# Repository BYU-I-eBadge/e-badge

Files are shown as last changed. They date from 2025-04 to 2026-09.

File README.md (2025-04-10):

# eBadge

**eBadge** is a customizable, hackable electronics badge designed for students to explore, build, and learn throughout their academic journey. It’s more than just a badge—it's a personal electronics lab, wearable project canvas, and long-term learning tool.

## Features

- Custom PCB with microcontroller 
- Modular peripherals: LEDs, sensors, buttons, displays, etc.
- Fully programmable with open-source firmware
- Designed for learning — from blinking LEDs to building full apps
- Battery-powered & portable — perfect for hacking on the go

## What’s in This Repo?

```bash
e-badge/
├── docs/           # Project documentation, setup guides, and images
├── hardware/       # Schematics, PCB layouts, BOMs, and 3D models
├── firmware/       # Embedded code for the badge's microcontroller
├── software/       # Host-side apps, test tools, or configurators
├── assets/         # Logos, badge graphics, and artwork
├── test/           # Scripts for testing hardware and firmware
├── LICENSE-CODE
├── LICENSE-HARDWARE
├── LICENSE-DOCS
├── README.md
└── .gitignore
```
## License

- **Hardware** – [CERN-OHL-S v2.0](./LICENSE-HARDWARE)
- **Firmware/Code** – [MIT License](./LICENSE-CODE)
- **Docs & Assets** – [CC BY-SA 4.0](./LICENSE-DOCS)

## Contributors

- Nathan Jack (jackn@byui.edu)
- Lynn Watson (watsonl@byui.edu)
- Jason Allred (allredjas@byui.edu)
- Richard Grimmett (grimmettr@byui.edu)
- Carl Gibbons (gibbonsc@byui.edu)
- Craig Lindstrom (lindstromc@byui.edu)
- Gary Godderidge (godderidgeg@byui.edu)
- Matt Manley (manleym@byui.edu)

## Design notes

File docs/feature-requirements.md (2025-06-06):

# eBadge Featureset

### MCU Features
* Wi-Fi/Bluetooth Capable
* JTAG single step debugging
* Dual Core (Defaults to Single Core)
* Supports MicroPython, Arduino IDE and RTOS!

### On-board Peripherals
* SPI Multicolor Screen (refresh >= 30 Hz)
* 6X Buttons with pull-down resistor configuration
* 2 LEDs
* 1 Tri-colored LED
* Speaker
* SD Card Slot
* Open slot of analog stick from Adafruit

### Interfaces
* 4pin JST/Grove Connectors 
* 2X Minibadge Connectors
* Lots of generic female headers!

### Additional Features
# Detailed Silk Screen
# Battery hook in + charging circuitry

### Unconfirmed Features
# Accelerometer
# Gyroscope
# RFID/NFC

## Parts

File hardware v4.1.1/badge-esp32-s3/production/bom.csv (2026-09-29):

Designator | Footprint | Quantity | Value | LCSC Part #
AL1, AL10, AL11, AL12, AL13, AL14, AL15, AL16, AL17, AL18, AL19, AL2, AL20, AL21, AL22, AL23, AL24, AL3, AL4, AL5, AL6, AL7, AL8, AL9 | LED-SMD_4P-SK6805MICRO-J | 24 | SK6805MICRO-J | C2909056
BUZZER1 | BUZ-SMD_L5.0-W5.5-P4.60 | 1 | MLT-5020 | C94598
C1, C12, C24, C39, C5, C6, C7 | C_0603 | 7 | 10uF | C96446
C10, C11, C25, C3, C35, C36, C4 | C_0402 | 7 | 100nF | C1525
C14, C2 | C_0603 | 2 | 100nF | C14663
C15, C16, C32, C33, C8, C9 | C_0402 | 6 | 1uF | C52923
C18, C19, C20, C21, C22, C23 | C_0603 | 6 | 1uF | C15849
C26 | C_0603 | 1 | 4.7uF | C19666
C28, C29, C30, C31, C38, C40 | C_0805 | 6 | 22uF | C296720
C34, C41, C44 | C_0402 | 3 | 100nF | C307331
C37 | C0603 | 1 | TMK107BBJ106MA-T | C386081
C42, C43, C45 | C_0805 | 3 | 10uF | C440198
CARD1 | TF-SMD_TF-PUSH | 1 | TF PUSH | C393941
CN1 | CONN-SMD_B4B-PH-SM4-TB-LF-SN | 1 | B4B-PH-SM4-TB (LF)(SN) | C160354
D1, D14, D19 | D_0603 | 3 | Red | C2286
D10 | D_SOD-523 | 1 | B5819WT | C7502714
D11 | SOD-523_L1.2-W0.8-LS1.6-RD-1 | 1 | MM5Z9V1T1G | C242268
D12 | D_0805 | 1 | Green | C2297
D13 | SMA_L4.3-W2.7-LS5.1-BI | 1 | SMAJ13CA | C19077534
D15, D20 | SOD-523F_L1.2-W0.8-LS1.7-RD | 2 | MM5Z5V1T1G | C146754
D16, D5 | D_SOD-123 | 2 | B0520W | C7502707
D17, D18 | SMAF_L3.5-W2.6-LS4.7-RD | 2 | SS32F_C719168 | C719168
D2, D3, D4, D6, D7, D8 | SOD-523_L1.2-W0.8-LS1.6-BI | 6 | LESD5D5.0CT1G | C5199850
D9 | SMA_L4.3-W2.7-LS5.1-BI | 1 | SMAJ5.0CA_C116601 | C116601
J1, J2 | TYPE-C-SMD_HX-TYPE-C-16PIN | 2 | Connector, USB-TYPE-C-16P | C2927039
J11 | PinSocket_2x03_P2.54mm_Vertical | 1 | Conn_02x03_Odd_Even | C541853
J12, J14, J15, J5 | PinSocket_1x02_P2.54mm_Vertical | 4 | Conn_01x02_Socket | C7499322
J13, J6 | PinSocket_1x04_P2.54mm_Vertical | 2 | Conn_01x04_Socket | C2718488
J3, J9 | PinSocket_2x06_P2.54mm_Vertical | 2 | Conn_02x06_Odd_Even | C5307342
J4 | PinSocket_2x15_P2.54mm_Vertical | 1 | Conn_02x15_Odd_Even | C7499350
J7, J8 | PinSocket_1x08_P2.54mm_Vertical | 2 | Conn_01x08_Socket | C42385698
L1 | IND-SMD_L4.0-W4.0 | 1 | ANR4030T3R9M | C6808101
L2 | L0805 | 1 | MPZ2012S101AT000 | C15957
L4 | IND-SMD_L4.1-W4.1_SPM40XX | 1 | FTC404020S1R5MGCA | C39676069
LED1 | LED-ARRAY-SMD_L3.7-W3.5-P1.10-TL | 1 | RS-3535MWAM | C842778
P1 | CONN-TH_2P-P2.00_PH-2A_C2319 | 1 | PH-2A_C2319 | C2319
P2 | FPC-SMD_12P-L11.5-W5.4-P0.50 | 1 | FPC 0.5MM 12P Pull type H2.0mm Pick up | C11086
P3 | CONN-TH_2P-P3.81_KF124-3.81-2P | 1 | WJ124-3.81-2P | C69811
Q1, Q2 | Q_SOT-23 | 2 | SS8050 200-350 | C2150
Q10 | SOT-23-3_L2.9-W1.6-P1.90-LS2.8-BR-CW | 1 | DMN3150L-7 | C156268
Q3 | DFN-3L_L1.0-W0.6-P0.65-BR | 1 | AP1606 | C2849580
Q5 | DTC114EE | 1 | DTC114E | C94400
Q7, Q8, Q9 | SOT-23-3_L2.9-W1.3-P1.90-LS2.4-BR | 3 | AO3415_C54938718 | C54938718
R1, R11, R12, R64 | R_0402 | 4 | 0Ω | C17168
R10, R13, R14, R17, R44, R46, R48, R6, R66, R68, R69, R70 | R_0402 | 12 | 10kΩ | C25744
R15, R16, R55 | R_0402 | 3 | 470Ω | C25117
R18, R20, R40, R47, R49, R50, R51, R52 | R_0402 | 8 | 100Ω | C25076
R2 | RES-ADJ-TH_3362P | 1 | 3362P-1-501_C48997906 | C48997906
R21, R24 | R_0402 | 2 | 47Ω | C25118
R22, R54 | R_0402 | 2 | 300Ω | C25102
R23 | JOYTICK-TH_YF16-DFL7.2-B5KO-45-10-B5KO-55--RG-A22 | 1 | YF16-FL7.2-B5KA(45-10)-R-A28 | C37323739
R25, R9 | R_0402 | 2 | 1kΩ | C11702
R26 | R_0402 | 1 | 2.2kΩ | C25879
R27, R28, R29, R30, R31, R32, R33, R34, R35, R36, R37, R38 | R_0603 | 12 | 10kΩ | C25804
R3, R4 | R_0402 | 2 | 5.1kΩ | C25905
R39, R53, R56, R60, R62 | R_0402 | 5 | 100kΩ | C25741
R41 | R_0402 | 1 | 150kΩ | C25755
R42 | 0402 | 1 | 27Ω
R43, R45 | R_0402 | 2 | 4.7kΩ | C25900
R5 | R0402 | 1 | 910k | C2909391
R58, R61 | R_0402 | 2 | 3.3kΩ | C25890
R59, R71 | R_0402 | 2 | 1MΩ | C26083
R63 | R_0402 | 1 | 39kΩ | C25783
R65 | R_0402 | 1 | 12kΩ | C25752
R67 | R_0402 | 1 | 68kΩ | C36871
R7 | R_0402 | 1 | 22kΩ | C25768
R8 | R_0402 | 1 | 47kΩ | C25792
SW1, SW2 | SW-SMD_L3.9-W3.0-P4.45 | 2 | TS-1088-AR02016 | C720477
SW10 | SW-TH_SK22D02G5 | 1 | SK22D02G5 | C22435630
SW4, SW5, SW6, SW7, SW8, SW9 | SW-TH_4P-L6.0-W6.0-P4.50-LS6.5 | 6 | TS665CJ | C393938
U1 | ESP32-S2-MINI-1 | 1 | ESP32-S3-MINI-1-N4R2 | C3013941
U11, U12 | SOT-23-6_L2.9-W1.6-P0.95-LS2.8-BL | 2 | SY6288F1ABC | C2875458
U18 | QFN-16_L3.0-W3.0-P0.50-TL_MMA8452QR1 | 1 | MMA8452QR1_C11360 | C11360
U2 | VQFN-HR-15_L3.0-W2.5-P0.50-BL_TPS63070RNMR | 1 | TPS630701RNMR | C2876599
U3 | QFN-28_L5.0-W5.0-P0.50-TL-EP3.3 | 1 | CP2102N-A02-GQFN28R | C964632
U4 | ESOP-8_L4.9-W3.9-P1.27-LS6.0-BL-EP | 1 | TP4056 | C16581
U5 | VQFN-HR-12_L2.5-W2.0-P0.50-BL | 1 | TPS2121RUXR | C485916
U6 | CONN-SMD_4P-P1.00_MEGASTAR_ZX-SH1.0-4PWT | 1 | ZX-SH1.0-4PWT | C7430446
U8 | X2QFN-12_L1.6-W1.6-P0.40-BL | 1 | TUSB321AIRWBR | C2674046
U9 | TSOT-26_L2.9-W1.6-P0.95-LS2.8-BL | 1 | AP63203WU-7 | C780769

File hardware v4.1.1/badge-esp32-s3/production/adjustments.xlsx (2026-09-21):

Designator | Man. Part | LCSC Part | New Man. Part | New LCSC Part
U11,U12 | SY6288F1ABC |  | SY6863B3ABC | C2687365
U9 | AP63201WU-7 |  | AP63203WU-7 | C780769
Q7,Q8,Q9 |  |  |  | C54938718

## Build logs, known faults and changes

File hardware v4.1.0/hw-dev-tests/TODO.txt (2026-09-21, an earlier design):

Change USB SRC LED resistor
Fix power rail dropping when changing pwr sources

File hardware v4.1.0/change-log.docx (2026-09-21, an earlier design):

E-Badge 4.1.0

Features

- Dual power roles on USB-CDC-DRD port
- VIN input from 2.8V to 16V
- Undervoltage and overvoltage protection.
- Overcurrent protection.
- 10W collective power budget from 5V and 3.3V rail. [^1]

Changes

- Adjusted Joystick footprint to match 3d model.
- Moved CN1 connector to not interfere with joystick.
- Adjusted resistors for RGB LED to lower brightness.
- Adjusted resistors for Red LED to increase brightness.
- Changed out previous 16mA per color channel Addressable LEDs for 5mA per color channel LEDs.
- Changed potentiometer to 500ohm 1 turn potentiometer. (This should make it much more responsive). [^2]
- Selected power path components to allow for increased current through the board. (More than 2A of current draw).
- Added automatic USB power role switching. The board can be powered from any source and source up 500mA of current to the USB-CDC-DRD port.
- Added VIN screw terminal input with respective components to allow for an external input voltage supply of 2.8V to 16V.
- Swapped 3.3V LDO for buck converter.
- Changed VBAT on E-badge to 5V. [^3]

[^1] The 5V rail can source 10W (5V at 2A). The 3.3V rail can source 6.6W (3.3V at 2A) but draws power from the 5V rail pulling from the 10W budget.
[^2] In my tests the buzzer seemed sufficiently load. But I was driving it with stm32 PWM rather than the ESP. Also, the buzzer is designed to resonate a 4khz so any other frequency will be significantly attenuated.
[^3] Changing this to 5V meets the E-badge specifications and allows for simplified routing and power management. Matthew Spotten

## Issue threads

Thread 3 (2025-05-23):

Additional I/O Pins

hyperdriveguy, 2025-05-23:

EverettButtars, 2025-06-02:
Slightly related, Here's a dump of potential extra sensors/parts that could be fun. All require only I2C + ground, but some offer additional functionality with more pins (typically interrupts).

Accelerometer: https://www.digikey.com/en/products/detail/memsic-inc/MXC4005XC/10322569
Rotary sensor: https://www.digikey.com/en/products/detail/infineon-technologies/TLV493DA1B6HTSA2/5887140
RFID/NFC: https://www.digikey.com/en/products/detail/stmicroelectronics/ST25DV64KC-IE6S3/14645761
Digi-Pot: https://www.digikey.com/en/products/detail/microchip-technology/MCP4561-502E-MS/2059913

Haven't found parts but off the top of my head:
Light sensors:
LED strip
Humidity/Moisture
Temprature

On another related front, here is Digikey's section on daughter boards. https://www.digikey.com/en/products/filter/expansion-boards-daughter-cards/797?s=N4IgTCBcDaIHIDEDCIC6BfIA

EverettButtars, 2025-06-03:
One thing I noticed on the pybadge was these headers on the back

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

These are pretty low profile and hook into almost all IO on the board. Something similar could be nice. Either under the screen for minimal impact due to through hole, or on the edge for bread board connection could be good. It could also be a solution to some 'plug and play' mini-badge-esc things.

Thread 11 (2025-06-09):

Alpha Board Software Test

hyperdriveguy, 2025-06-09:
Make test firmware to expose hardware bugs in our design.

Closed 2025-06-23.

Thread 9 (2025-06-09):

Cost Optimization For Beta Board

hyperdriveguy, 2025-06-09:
We need to find ways to cut costs for this version for both small scale and full scale production.

hyperdriveguy, 2025-06-09:
Changes that were made taking this consideration into account include:
* Switching from a ESP32-S3-WROOM-1 to ESP32-S3-MINI-1 package
* Selecting basic parts over extended parts
* Selecting high availability parts to replace less available and more costly parts

Closed 2025-06-30.

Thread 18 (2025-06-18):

Fix Alphaboard

ThirstyShades, 2025-06-18:
The Alpha board was laid out incorrectly and needs traces to be fixed.

Specifically, the UART and the linear regulator, as well as any other issues that might arise, are addressed in hopes of interfacing with the SPI screen.

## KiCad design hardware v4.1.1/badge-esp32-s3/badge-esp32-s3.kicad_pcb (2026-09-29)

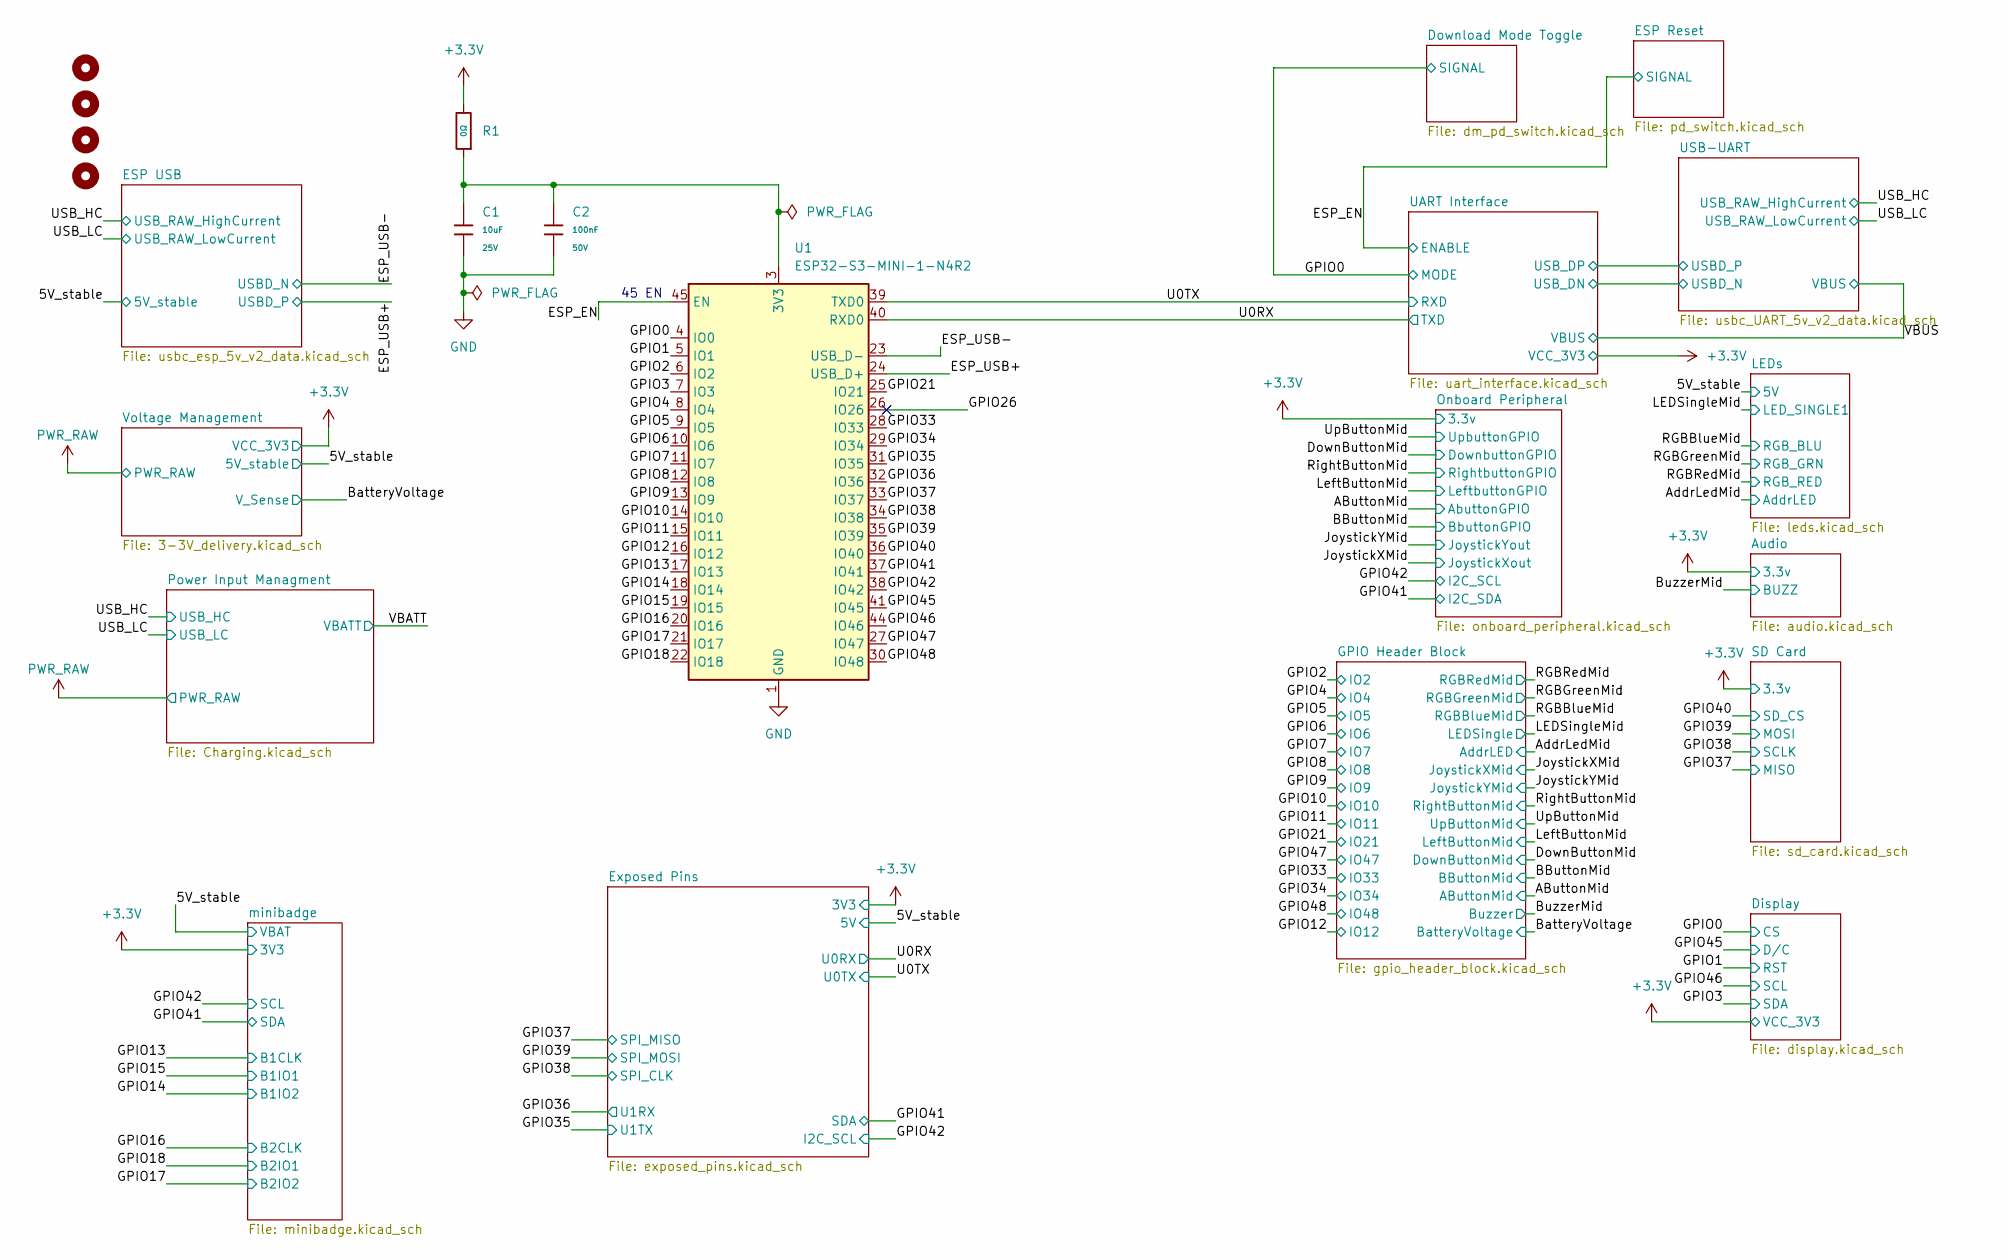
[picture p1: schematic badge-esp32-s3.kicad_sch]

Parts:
C1: 10uF; C_0603; Voltage Rated 25V; Tolerance ±20%; Part CL10A106MA8NRNC; LCSC C96446
C2: 100nF; C_0603; Voltage Rated 50V; Tolerance ±10%; Part CC0603KRX7R9BB104; LCSC C14663
H1, H2, H3, H4: MountingHole; MountingHole_3.2mm_M3_ISO7380_Pad_TopBottom
R1: 0Ω; R_0402; Overload Voltage (Max) 50V; Tolerance ±1%; Part 0402WGF0000TCE; LCSC C17168
U1: ESP32-S3-MINI-1-N4R2; ESP32-S2-MINI-1; LCSC Part C3013941

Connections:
+3.3V: R1.2; also elsewhere on the board
/ESP_EN: U1.45 (EN); also elsewhere on the board
/ESP_USB+: U1.24 (USB_D+); also elsewhere on the board
/ESP_USB-: U1.23 (USB_D-); also elsewhere on the board
/GPIO0: U1.4 (IO0); also elsewhere on the board
/GPIO1: U1.5 (IO1); also elsewhere on the board
/GPIO2: U1.6 (IO2); also elsewhere on the board
/GPIO3: U1.7 (IO3); also elsewhere on the board
/GPIO4: U1.8 (IO4); also elsewhere on the board
/GPIO5: U1.9 (IO5); also elsewhere on the board
/GPIO6: U1.10 (IO6); also elsewhere on the board
/GPIO7: U1.11 (IO7); also elsewhere on the board
/GPIO8: U1.12 (IO8); also elsewhere on the board
/GPIO9: U1.13 (IO9); also elsewhere on the board
/GPIO10: U1.14 (IO10); also elsewhere on the board
/GPIO11: U1.15 (IO11); also elsewhere on the board
/GPIO12: U1.16 (IO12); also elsewhere on the board
/GPIO13: U1.17 (IO13); also elsewhere on the board
/GPIO14: U1.18 (IO14); also elsewhere on the board
/GPIO15: U1.19 (IO15); also elsewhere on the board
/GPIO16: U1.20 (IO16); also elsewhere on the board
/GPIO17: U1.21 (IO17); also elsewhere on the board
/GPIO18: U1.22 (IO18); also elsewhere on the board
/GPIO21: U1.25 (IO21); also elsewhere on the board
/GPIO26: U1.26 (IO26)
/GPIO33: U1.28 (IO33); also elsewhere on the board
/GPIO34: U1.29 (IO34); also elsewhere on the board
/GPIO35: U1.31 (IO35); also elsewhere on the board
/GPIO36: U1.32 (IO36); also elsewhere on the board
/GPIO37: U1.33 (IO37); also elsewhere on the board
/GPIO38: U1.34 (IO38); also elsewhere on the board
/GPIO39: U1.35 (IO39); also elsewhere on the board
/GPIO40: U1.36 (IO40); also elsewhere on the board
/GPIO41: U1.37 (IO41); also elsewhere on the board
/GPIO42: U1.38 (IO42); also elsewhere on the board
/GPIO45: U1.41 (IO45); also elsewhere on the board
/GPIO46: U1.44 (IO46); also elsewhere on the board
/GPIO47: U1.27 (IO47); also elsewhere on the board
/GPIO48: U1.30 (IO48); also elsewhere on the board
/U0RX: U1.40 (RXD0); also elsewhere on the board
/U0TX: U1.39 (TXD0); also elsewhere on the board
GND: C1.2, C2.2, U1.1 (GND), U1.2 (GND), U1.42 (GND), U1.43 (GND), U1.46 (GND), U1.47 (GND), U1.48 (GND), U1.49 (GND), U1.50 (GND), U1.51 (GND), U1.52 (GND), U1.53 (GND), U1.54 (GND), U1.55 (GND), U1.56 (GND), U1.57 (GND), U1.58 (GND), U1.59 (GND), U1.60 (GND), U1.61 (GND), U1.62 (GND), U1.63 (GND), U1.64 (GND), U1.65 (GND); also elsewhere on the board
unnamed: C1.1, C2.1, R1.1, U1.3 (3V3)

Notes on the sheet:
45 EN

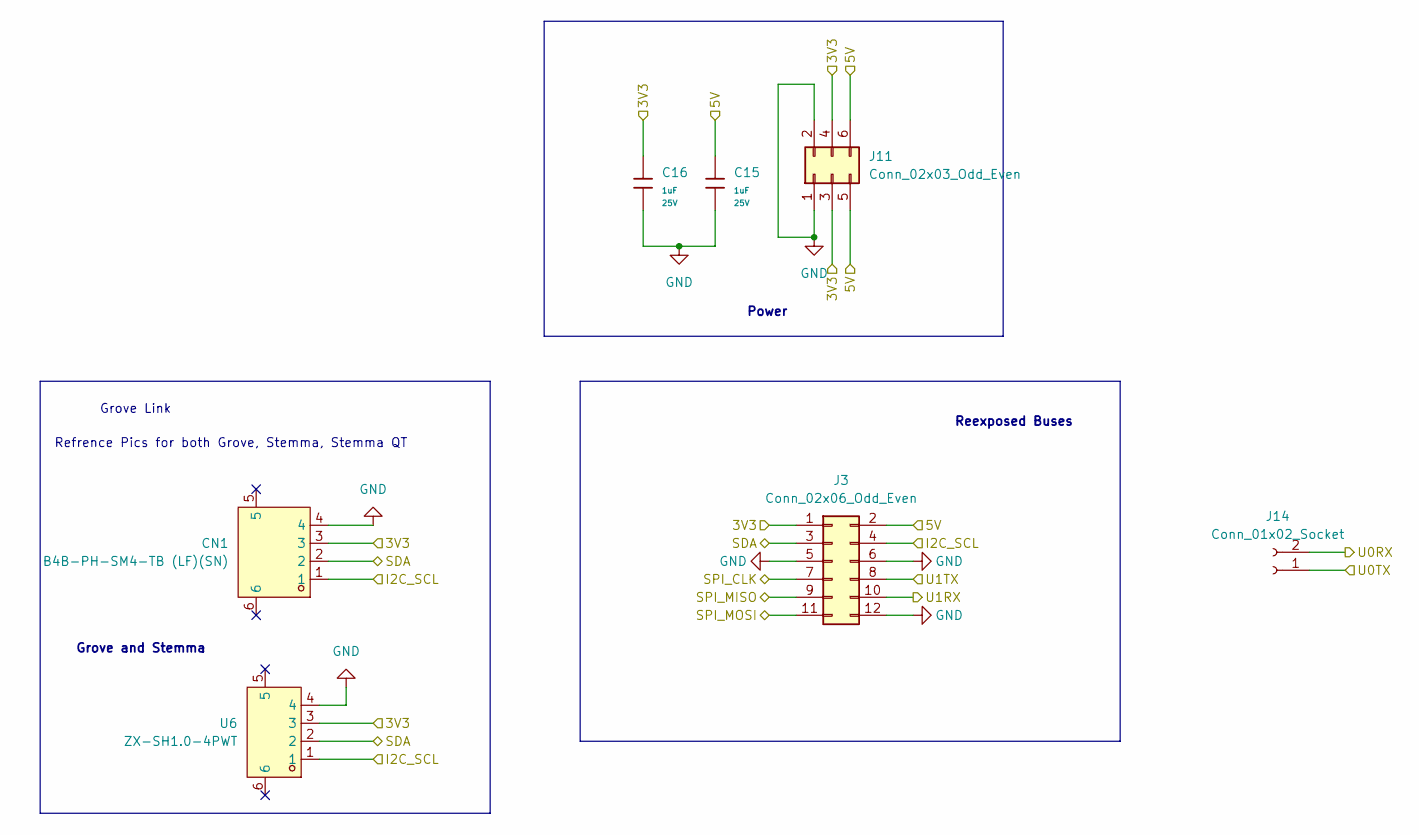
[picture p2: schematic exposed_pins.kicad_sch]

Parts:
C15, C16: 1uF; C_0402; Voltage Rated 25V; Tolerance ±10%; Part CL05A105KA5NQNC; LCSC C52923
CN1: B4B-PH-SM4-TB (LF)(SN); CONN-SMD_B4B-PH-SM4-TB-LF-SN; LCSC Part C160354
J3: Conn_02x06_Odd_Even; PinSocket_2x06_P2.54mm_Vertical; LCSC C5307342
J11: Conn_02x03_Odd_Even; PinSocket_2x03_P2.54mm_Vertical; LCSC C541853
J14: Conn_01x02_Socket; PinSocket_1x02_P2.54mm_Vertical; LCSC C7499322
U6: ZX-SH1.0-4PWT; CONN-SMD_4P-P1.00_MEGASTAR_ZX-SH1.0-4PWT; LCSC Part C7430446

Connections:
+3.3V: C16.1, CN1.3, J3.1, J11.3, J11.4, U6.3; also elsewhere on the board
/5V_stable: C15.1, J3.2, J11.5, J11.6; also elsewhere on the board
/GPIO35: J3.8; also elsewhere on the board
/GPIO36: J3.10; also elsewhere on the board
/GPIO37: J3.9; also elsewhere on the board
/GPIO38: J3.7; also elsewhere on the board
/GPIO39: J3.11; also elsewhere on the board
/GPIO41: CN1.2, J3.3, U6.2; also elsewhere on the board
/GPIO42: CN1.1, J3.4, U6.1; also elsewhere on the board
/U0RX: J14.2; also elsewhere on the board
/U0TX: J14.1; also elsewhere on the board
GND: C15.2, C16.2, CN1.4, J3.5, J3.6, J3.12, J11.1, J11.2, U6.4; also elsewhere on the board

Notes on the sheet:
Power
Reexposed Buses
Refrence Pics for both Grove, Stemma, Stemma QT
Grove Link
Grove and Stemma

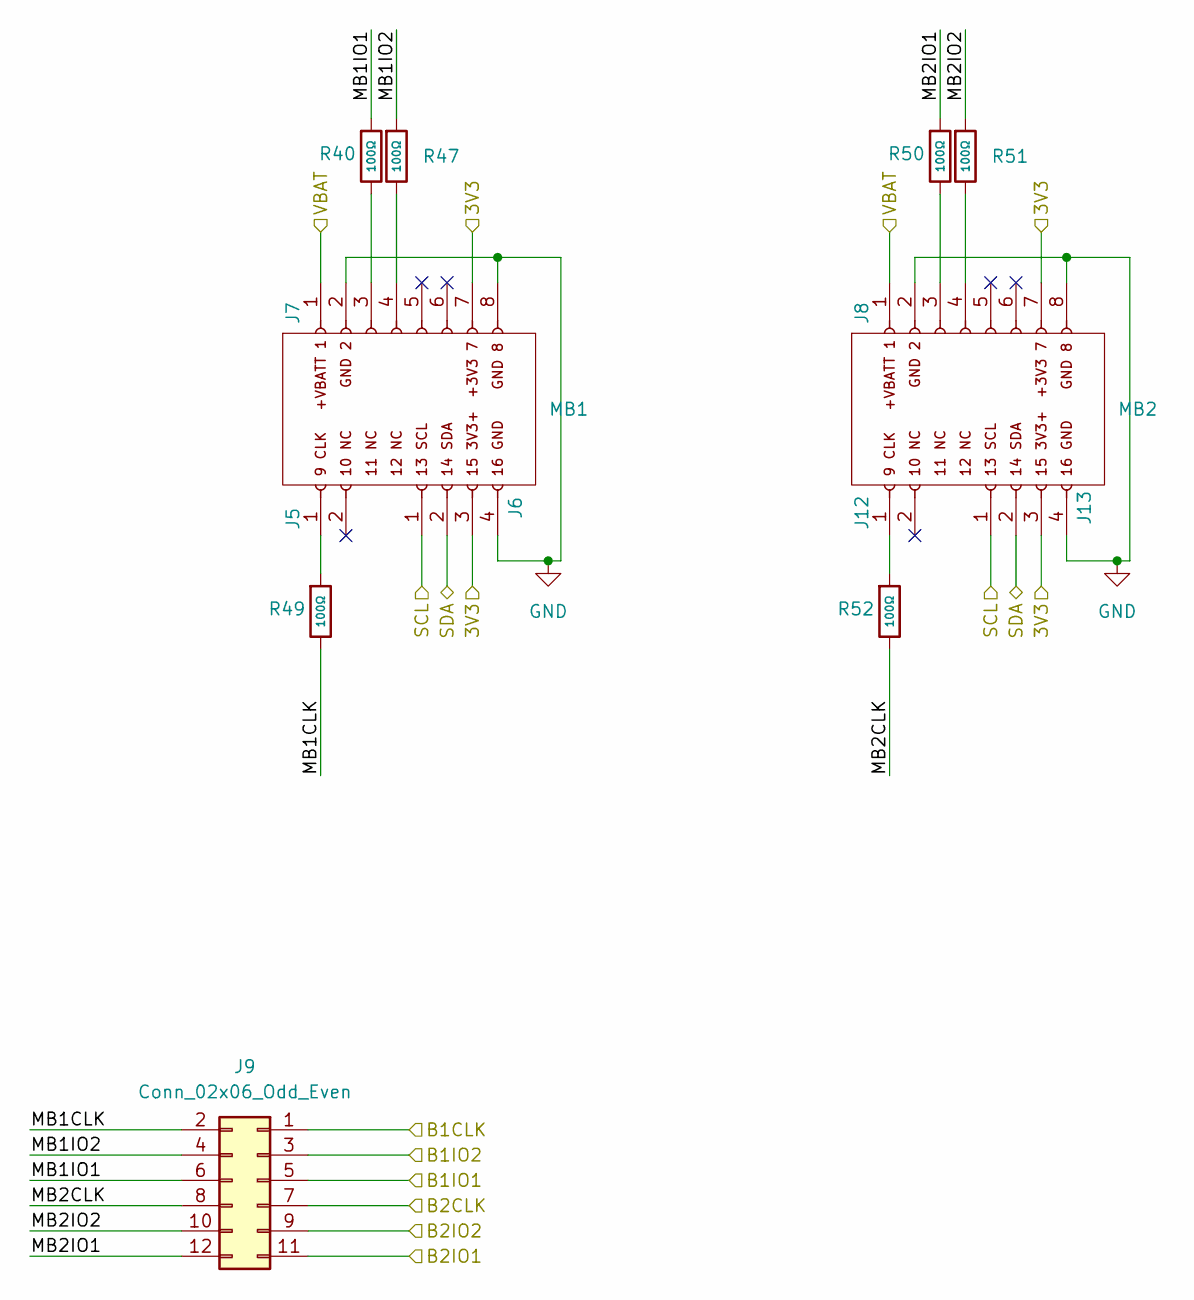
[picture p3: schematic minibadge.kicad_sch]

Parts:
J5, J12: Conn_01x02_Socket; PinSocket_1x02_P2.54mm_Vertical; LCSC C7499322
J6, J13: Conn_01x04_Socket; PinSocket_1x04_P2.54mm_Vertical; LCSC C2718488
J7, J8: Conn_01x08_Socket; PinSocket_1x08_P2.54mm_Vertical; LCSC C42385698
J9: Conn_02x06_Odd_Even; PinSocket_2x06_P2.54mm_Vertical; LCSC C5307342
MB1, MB2: MiniBadge_Full; MiniBadge_Full_NoEdges
R40, R47, R49, R50, R51, R52: 100Ω; R_0402; Overload Voltage (Max) 50V; Tolerance ±1%; Part 0402WGF1000TCE; LCSC C25076

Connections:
+3.3V: J6.3, J7.7, J8.7, J13.3; also elsewhere on the board
/5V_stable: J7.1, J8.1; also elsewhere on the board
/GPIO13: J9.1; also elsewhere on the board
/GPIO14: J9.3; also elsewhere on the board
/GPIO15: J9.5; also elsewhere on the board
/GPIO16: J9.7; also elsewhere on the board
/GPIO17: J9.9; also elsewhere on the board
/GPIO18: J9.11; also elsewhere on the board
/GPIO41: J6.2, J13.2; also elsewhere on the board
/GPIO42: J6.1, J13.1; also elsewhere on the board
/minibadge/MB1CLK: J9.2, R49.2
/minibadge/MB1IO1: J9.6, R40.1
/minibadge/MB1IO2: J9.4, R47.1
/minibadge/MB2CLK: J9.8, R52.2
/minibadge/MB2IO1: J9.12, R50.1
/minibadge/MB2IO2: J9.10, R51.1
GND: J6.4, J7.2, J7.8, J8.2, J8.8, J13.4; also elsewhere on the board
unnamed: J5.1, R49.1
unnamed: J7.3, R40.2
unnamed: J7.4, R47.2
unnamed: J8.3, R50.2
unnamed: J8.4, R51.2
unnamed: J12.1, R52.1

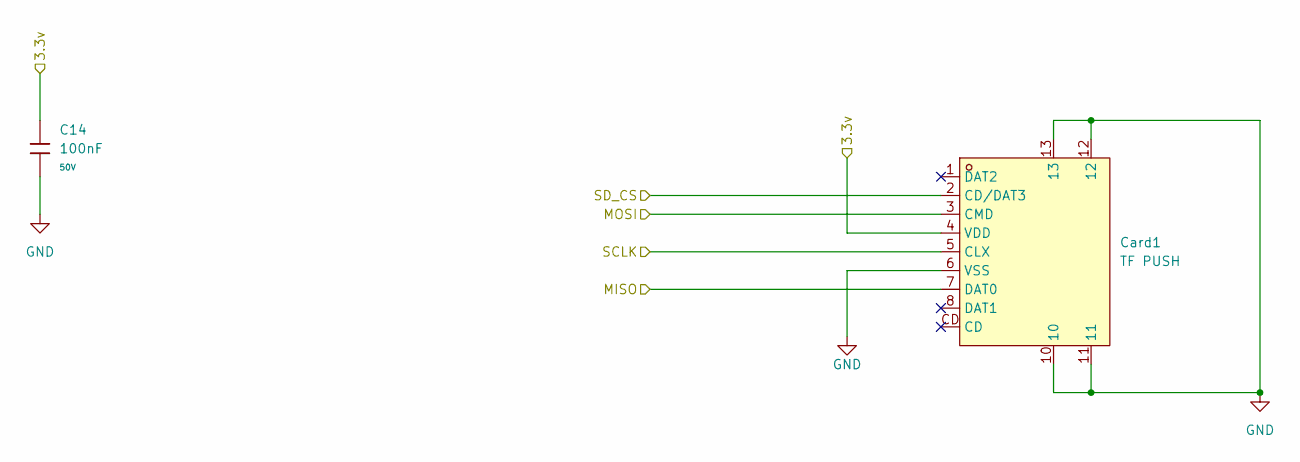
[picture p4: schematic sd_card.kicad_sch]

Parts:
C14: 100nF; C_0603; Voltage Rated 50V; Tolerance ±10%; Part CC0603KRX7R9BB104; LCSC C14663
Card1: TF PUSH; TF-SMD_TF-PUSH; LCSC Part C393941

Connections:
+3.3V: C14.1, Card1.4 (VDD); also elsewhere on the board
/GPIO37: Card1.7 (DAT0); also elsewhere on the board
/GPIO38: Card1.5 (CLX); also elsewhere on the board
/GPIO39: Card1.3 (CMD); also elsewhere on the board
/GPIO40: Card1.2 (CD/DAT3); also elsewhere on the board
GND: C14.2, Card1.6 (VSS), Card1.10, Card1.11, Card1.12, Card1.13; also elsewhere on the board

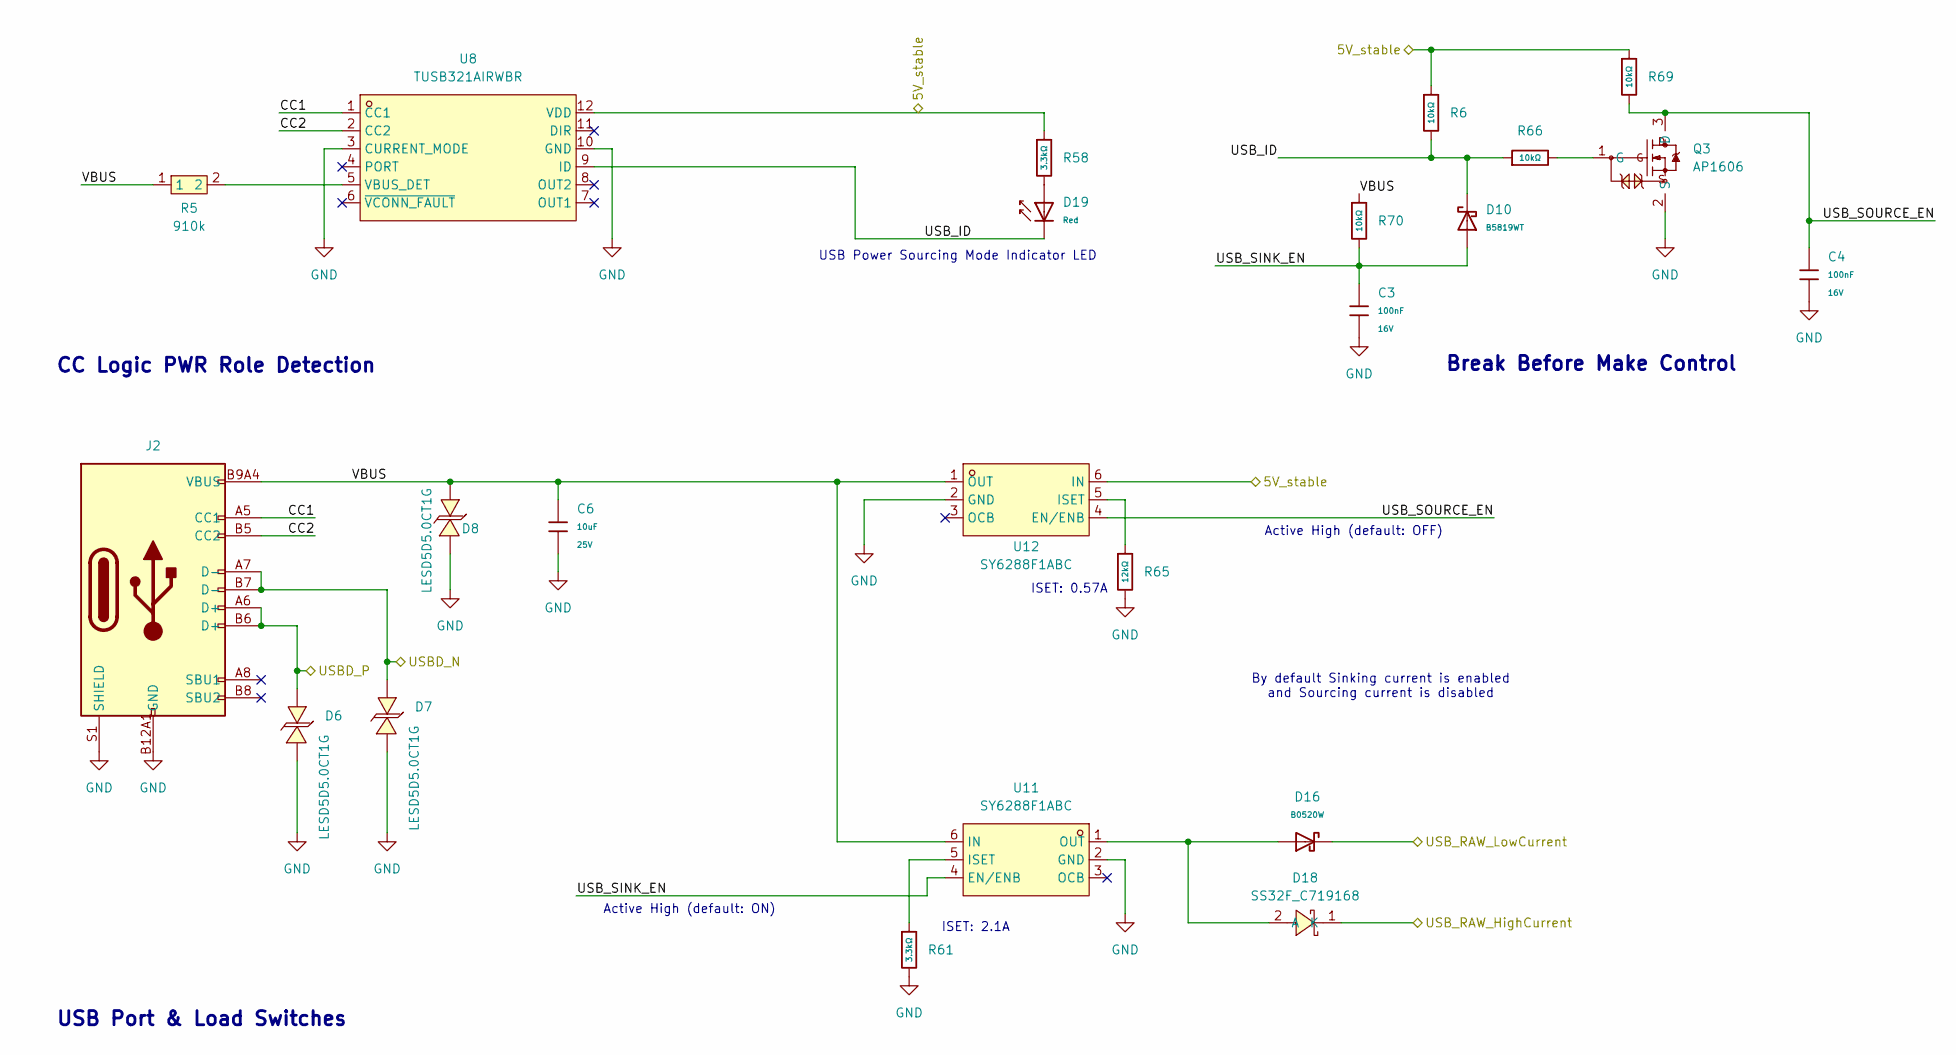
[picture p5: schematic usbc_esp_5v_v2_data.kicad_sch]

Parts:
C3, C4: 100nF; C_0402; Voltage Rated 16V; Tolerance ±10%; Part CL05B104KO5NNNC; LCSC C1525
C6: 10uF; C_0603; Voltage Rated 25V; Tolerance ±20%; Part CL10A106MA8NRNC; LCSC C96446
D6, D7, D8: LESD5D5.0CT1G; SOD-523_L1.2-W0.8-LS1.6-BI; LCSC Part C5199850
D10: B5819WT; D_SOD-523; Part B5819WT; LCSC C7502714
D16: B0520W; D_SOD-123; Part B0520W; LCSC C7502707
D18: SS32F_C719168; SMAF_L3.5-W2.6-LS4.7-RD; MPN SS32F; LCSC Part C719168
D19: Red; D_0603; Part KT-0603R; LCSC C2286
J2: Connector, USB-TYPE-C-16P; TYPE-C-SMD_HX-TYPE-C-16PIN; LCSC C2927039
Q3: AP1606; DFN-3L_L1.0-W0.6-P0.65-BR; MPN AP1606; LCSC Part C2849580
R5: 910k; R0402; MPN FRC0402F9103TS; LCSC Part C2909391
R6, R66, R69, R70: 10kΩ; R_0402; Overload Voltage (Max) 50V; Tolerance ±1%; Part 0402WGF1002TCE; LCSC C25744
R58, R61: 3.3kΩ; R_0402; Overload Voltage (Max) 50V; Tolerance ±1%; Part 0402WGF3301TCE; LCSC C25890
R65: 12kΩ; R_0402; Overload Voltage (Max) 50V; Tolerance ±1%; Part 0402WGF1202TCE; LCSC C25752
U8: TUSB321AIRWBR; X2QFN-12_L1.6-W1.6-P0.40-BL; MPN TUSB321AIRWBR; LCSC Part C2674046
U11, U12: SY6288F1ABC; SOT-23-6_L2.9-W1.6-P0.95-LS2.8-BL; MPN SY6288F1ABC; LCSC Part C2875458

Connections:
/5V_stable: R6.1, R58.1, R69.1, U8.12 (VDD), U12.6 (IN); also elsewhere on the board
/ESP USB/CC1: J2.A5 (CC1), U8.1 (CC1)
/ESP USB/CC2: J2.B5 (CC2), U8.2 (CC2)
/ESP USB/USB_ID: D10.1, D19.1, R6.2, R66.1, U8.9 (ID)
/ESP USB/USB_SINK_EN: C3.1, D10.2, R70.2, U11.4 (EN/ENB)
/ESP USB/USB_SOURCE_EN: C4.1, Q3.3 (D), R69.2, U12.4 (EN/ENB)
/ESP USB/VBUS: C6.1, D8.2, J2.A9B4 (VBUS), J2.B9A4 (VBUS), R5.1, R70.1, U11.6 (IN), U12.1 (OUT)
/ESP_USB+: D6.2, J2.A6 (D+), J2.B6 (D+); also elsewhere on the board
/ESP_USB-: D7.2, J2.A7 (D-), J2.B7 (D-); also elsewhere on the board
/USB_HC: D18.1 (K); also elsewhere on the board
/USB_LC: D16.1; also elsewhere on the board
GND: C3.2, C4.2, C6.2, D6.1, D7.1, D8.1, J2.A12B1 (GND), J2.B12A1 (GND), J2.S1 (SHIELD), Q3.2 (S), R61.2, R65.2, U8.3 (CURRENT_MODE), U8.10 (GND), U11.2 (GND), U12.2 (GND); also elsewhere on the board
unnamed: D16.2, D18.2 (A), U11.1 (OUT)
unnamed: D19.2, R58.2
unnamed: Q3.1 (G), R66.2
unnamed: R5.2, U8.5 (VBUS_DET)
unnamed: R61.1, U11.5 (ISET)
unnamed: R65.1, U12.5 (ISET)

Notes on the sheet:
Active High (default: OFF)
USB Power Sourcing Mode Indicator LED
By default Sinking current is enabled and Sourcing current is disabled
ISET: 2.1A
Active High (default: ON)
Break Before Make Control
ISET: 0.57A
CC Logic PWR Role Detection
USB Port & Load Switches

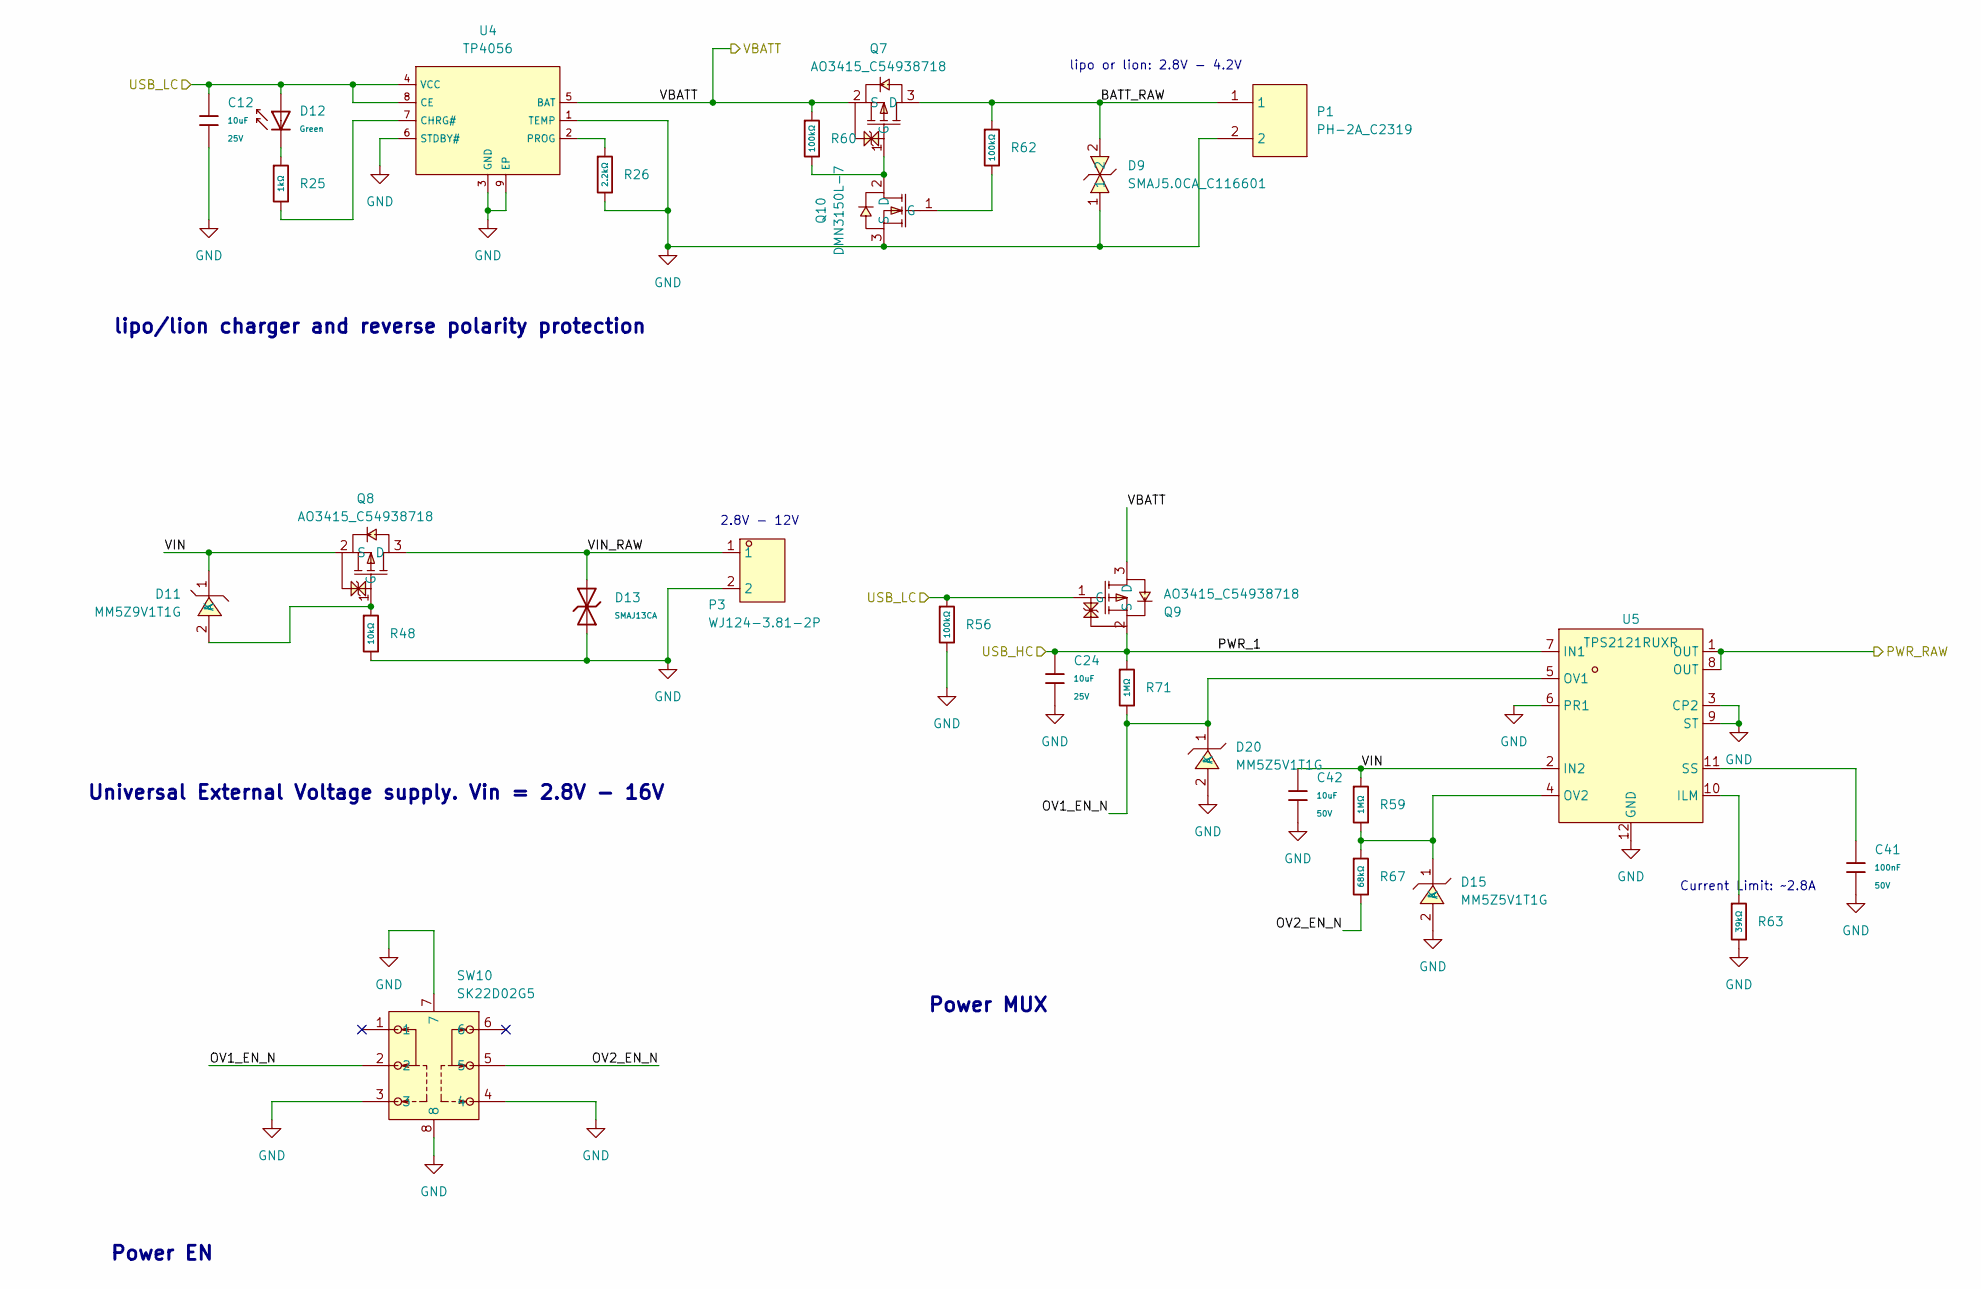
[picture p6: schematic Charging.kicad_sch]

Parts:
C12, C24: 10uF; C_0603; Voltage Rated 25V; Tolerance ±20%; Part CL10A106MA8NRNC; LCSC C96446
C41: 100nF; C_0402; Voltage Rated 50V; Tolerance ±10%; Part CL05B104KB54PNC; LCSC C307331
C42: 10uF; C_0805; Voltage Rated 50V; Tolerance ±10%; Part GRM21BR61H106KE43L; LCSC C440198
D9: SMAJ5.0CA_C116601; SMA_L4.3-W2.7-LS5.1-BI; MPN SMAJ5.0CA; LCSC Part C116601
D11: MM5Z9V1T1G; SOD-523_L1.2-W0.8-LS1.6-RD-1; MPN MM5Z9V1T1G; LCSC Part C242268
D12: Green; D_0805; Part KT-0805G; LCSC C2297
D13: SMAJ13CA; SMA_L4.3-W2.7-LS5.1-BI; Part SMAJ13CA; LCSC C19077534
D15, D20: MM5Z5V1T1G; SOD-523F_L1.2-W0.8-LS1.7-RD; MPN MM5Z5V1T1G; LCSC Part C146754
P1: PH-2A_C2319; CONN-TH_2P-P2.00_PH-2A_C2319; LCSC Part C2319
P3: WJ124-3.81-2P; CONN-TH_2P-P3.81_KF124-3.81-2P; MPN WJ124-3.81-02P-14-00A; LCSC Part C69811
Q7, Q8, Q9: AO3415_C54938718; SOT-23-3_L2.9-W1.3-P1.90-LS2.4-BR; MPN AO3415; LCSC Part C54938718
Q10: DMN3150L-7; SOT-23-3_L2.9-W1.6-P1.90-LS2.8-BR-CW; MPN DMN3150L-7; LCSC Part C156268
R25: 1kΩ; R_0402; Overload Voltage (Max) 50V; Tolerance ±1%; Part 0402WGF1001TCE; LCSC C11702
R26: 2.2kΩ; R_0402; Overload Voltage (Max) 50V; Tolerance ±1%; Part 0402WGF2201TCE; LCSC C25879
R48: 10kΩ; R_0402; Overload Voltage (Max) 50V; Tolerance ±1%; Part 0402WGF1002TCE; LCSC C25744
R56, R60, R62: 100kΩ; R_0402; Overload Voltage (Max) 50V; Tolerance ±1%; Part 0402WGF1003TCE; LCSC C25741
R59, R71: 1MΩ; R_0402; Overload Voltage (Max) 50V; Tolerance ±1%; Part 0402WGF1004TCE; LCSC C26083
R63: 39kΩ; R_0402; Overload Voltage (Max) 50V; Tolerance ±1%; Part 0402WGF3902TCE; LCSC C25783
R67: 68kΩ; R_0402; Overload Voltage (Max) 50V; Tolerance ±1%; Part 0402WGF6802TCE; LCSC C36871
SW10: SK22D02G5; SW-TH_SK22D02G5; MPN SK22D02G5; LCSC Part C22435630
U4: TP4056; ESOP-8_L4.9-W3.9-P1.27-LS6.0-BL-EP; Part TP4056-42-ESOP8; LCSC C16581
U5: TPS2121RUXR; VQFN-HR-12_L2.5-W2.0-P0.50-BL; MPN TPS2121RUXR; LCSC Part C485916

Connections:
/Power Input Managment/BATT_RAW: D9.2, P1.1, Q7.3 (D), R62.1
/Power Input Managment/OV1_EN_N: D20.1 (K), R71.2, SW10.2, U5.5 (OV1)
/Power Input Managment/OV2_EN_N: R67.2, SW10.5
/Power Input Managment/VIN: C42.1, D11.1 (K), Q8.2 (S), R59.1, U5.2 (IN2)
/Power Input Managment/VIN_RAW: D13.2, P3.1, Q8.3 (D)
/USB_HC: C24.1, Q9.2 (S), R71.1, U5.7 (IN1); also elsewhere on the board
/USB_LC: C12.1, D12.2, Q9.1 (G), R56.1, U4.4 (VCC), U4.8 (CE); also elsewhere on the board
/VBATT: Q7.2 (S), Q9.3 (D), R60.1, U4.5 (BAT)
GND: C12.2, C24.2, C41.2, C42.2, D9.1, D13.1, D15.2 (A), D20.2 (A), P1.2, P3.2, Q10.3 (S), R26.2, R48.2, R56.2, R63.2, SW10.3, SW10.4, SW10.7, SW10.8, U4.1 (TEMP), U4.3 (GND), U4.6 (STDBY#), U4.9 (EP), U5.3 (CP2), U5.6 (PR1), U5.9 (ST), U5.12 (GND); also elsewhere on the board
unnamed: D11.2 (A), Q8.1 (G), R48.1
unnamed: D12.1, R25.1
unnamed: D15.1 (K), R59.2, R67.1, U5.4 (OV2)
unnamed: Q7.1 (G), Q10.2 (D), R60.2
unnamed: Q10.1 (G), R62.2
unnamed: R25.2, U4.7 (CHRG#)
unnamed: R26.1, U4.2 (PROG)
unnamed: R63.1, U5.10 (ILM)
unnamed: C41.1, U5.11 (SS)
PWR_RAW: U5.1 (OUT), U5.8 (OUT); also elsewhere on the board

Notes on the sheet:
2.8V - 12V
lipo or lion: 2.8V - 4.2V
Universal External Voltage supply. Vin = 2.8V - 16V
Power EN
lipo/lion charger and reverse polarity protection
Current Limit: ~2.8A
Power MUX

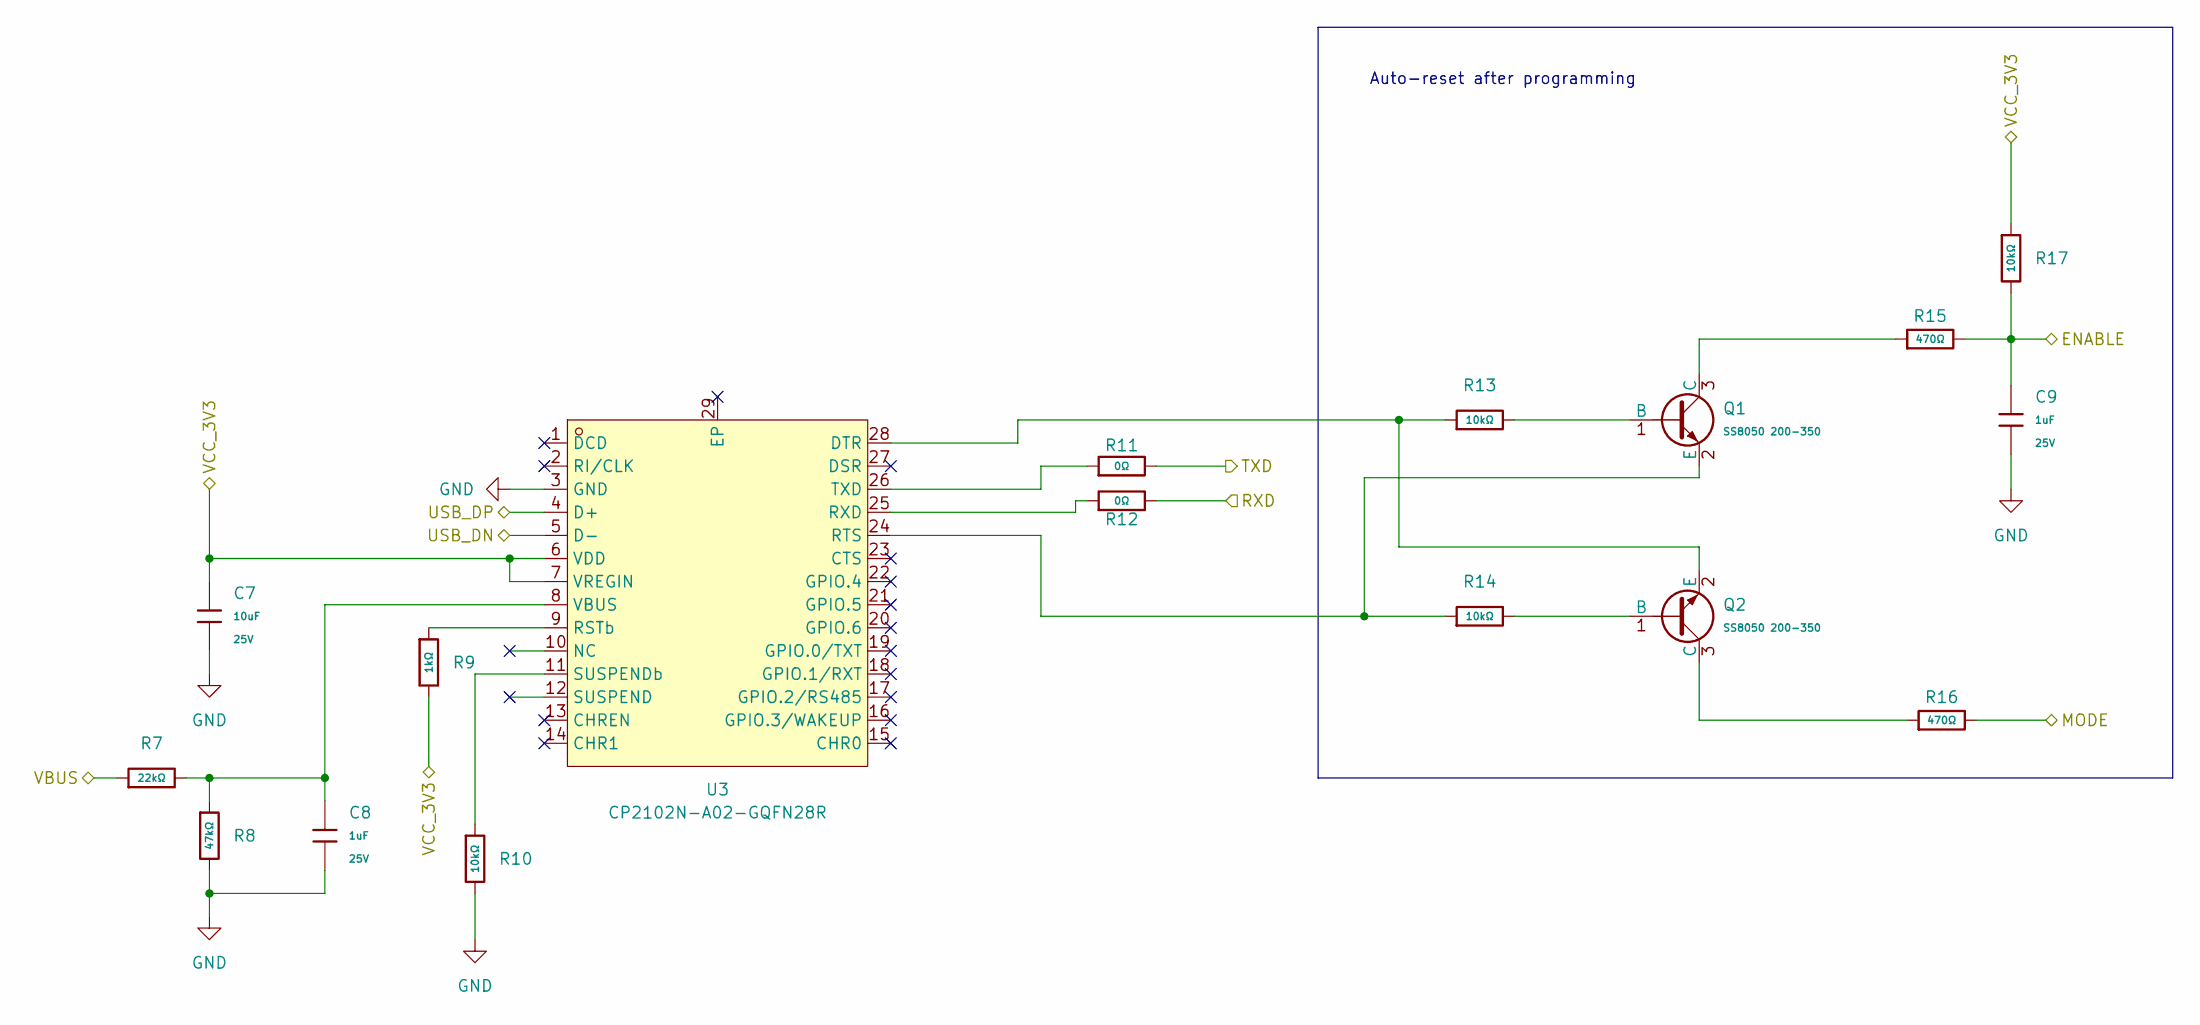
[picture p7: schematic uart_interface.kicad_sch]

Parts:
C7: 10uF; C_0603; Voltage Rated 25V; Tolerance ±20%; Part CL10A106MA8NRNC; LCSC C96446
C8, C9: 1uF; C_0402; Voltage Rated 25V; Tolerance ±10%; Part CL05A105KA5NQNC; LCSC C52923
Q1, Q2: SS8050 200-350; Q_SOT-23; Part SS8050(RANGE:200-350); LCSC C2150
R7: 22kΩ; R_0402; Overload Voltage (Max) 50V; Tolerance ±1%; Part 0402WGF2202TCE; LCSC C25768
R8: 47kΩ; R_0402; Overload Voltage (Max) 50V; Tolerance ±1%; Part 0402WGF4702TCE; LCSC C25792
R9: 1kΩ; R_0402; Overload Voltage (Max) 50V; Tolerance ±1%; Part 0402WGF1001TCE; LCSC C11702
R10, R13, R14, R17: 10kΩ; R_0402; Overload Voltage (Max) 50V; Tolerance ±1%; Part 0402WGF1002TCE; LCSC C25744
R11, R12: 0Ω; R_0402; Overload Voltage (Max) 50V; Tolerance ±1%; Part 0402WGF0000TCE; LCSC C17168
R15, R16: 470Ω; R_0402; Overload Voltage (Max) 50V; Tolerance ±1%; Part 0402WGF4700TCE; LCSC C25117
U3: CP2102N-A02-GQFN28R; QFN-28_L5.0-W5.0-P0.50-TL-EP3.3; LCSC Part C964632

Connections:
+3.3V: C7.1, R9.2, R17.1, U3.6 (VDD), U3.7 (VREGIN); also elsewhere on the board
/ESP_EN: C9.1, R15.2, R17.2; also elsewhere on the board
/GPIO0: R16.2; also elsewhere on the board
/U0RX: R11.2; also elsewhere on the board
/U0TX: R12.2; also elsewhere on the board
/UART Interface/USB_DN: U3.5 (D-); also elsewhere on the board
/UART Interface/USB_DP: U3.4 (D+); also elsewhere on the board
/VBUS: R7.1; also elsewhere on the board
GND: C7.2, C8.2, C9.2, R8.2, R10.2, U3.3 (GND); also elsewhere on the board
unnamed: Q1.1 (B), R13.2
unnamed: Q1.3 (C), R15.1
unnamed: Q1.2 (E), R14.1, U3.24 (RTS)
unnamed: Q2.1 (B), R14.2
unnamed: Q2.3 (C), R16.1
unnamed: Q2.2 (E), R13.1, U3.28 (DTR)
unnamed: R9.1, U3.9 (RSTb)
unnamed: R12.1, U3.25 (RXD)
unnamed: R10.1, U3.11 (SUSPENDb)
unnamed: R11.1, U3.26 (TXD)
unnamed: C8.1, R7.2, R8.1, U3.8 (VBUS)

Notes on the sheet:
Auto-reset after programming

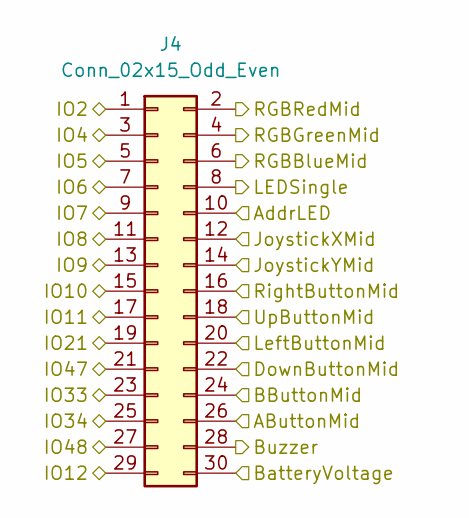
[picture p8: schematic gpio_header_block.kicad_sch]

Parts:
J4: Conn_02x15_Odd_Even; PinSocket_2x15_P2.54mm_Vertical; LCSC Part C7499350

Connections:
/AButtonMid: J4.26; also elsewhere on the board
/AddrLedMid: J4.10; also elsewhere on the board
/BButtonMid: J4.24; also elsewhere on the board
/BatteryVoltage: J4.30; also elsewhere on the board
/BuzzerMid: J4.28; also elsewhere on the board
/DownButtonMid: J4.22; also elsewhere on the board
/GPIO2: J4.1; also elsewhere on the board
/GPIO4: J4.3; also elsewhere on the board
/GPIO5: J4.5; also elsewhere on the board
/GPIO6: J4.7; also elsewhere on the board
/GPIO7: J4.9; also elsewhere on the board
/GPIO8: J4.11; also elsewhere on the board
/GPIO9: J4.13; also elsewhere on the board
/GPIO10: J4.15; also elsewhere on the board
/GPIO11: J4.17; also elsewhere on the board
/GPIO12: J4.29; also elsewhere on the board
/GPIO21: J4.19; also elsewhere on the board
/GPIO33: J4.23; also elsewhere on the board
/GPIO34: J4.25; also elsewhere on the board
/GPIO47: J4.21; also elsewhere on the board
/GPIO48: J4.27; also elsewhere on the board
/JoystickXMid: J4.12; also elsewhere on the board
/JoystickYMid: J4.14; also elsewhere on the board
/LEDSingleMid: J4.8; also elsewhere on the board
/LeftButtonMid: J4.20; also elsewhere on the board
/RGBBlueMid: J4.6; also elsewhere on the board
/RGBGreenMid: J4.4; also elsewhere on the board
/RGBRedMid: J4.2; also elsewhere on the board
/RightButtonMid: J4.16; also elsewhere on the board
/UpButtonMid: J4.18; also elsewhere on the board

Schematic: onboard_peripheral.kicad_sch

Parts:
J15: Conn_01x02_Socket; PinSocket_1x02_P2.54mm_Vertical; LCSC C7499322

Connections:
/Onboard Peripheral/Accelormeter/INT 1 (output to MCU, NN): J15.2; also elsewhere on the board
/Onboard Peripheral/Accelormeter/INT 2 (output to MCU, NN): J15.1; also elsewhere on the board

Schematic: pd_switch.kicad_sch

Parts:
C36: 100nF; C_0402; Voltage Rated 16V; Tolerance ±10%; Part CL05B104KO5NNNC; LCSC C1525
SW2: TS-1088-AR02016; SW-SMD_L3.9-W3.0-P4.45; LCSC Part C720477

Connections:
/ESP_EN: C36.2, SW2.2; also elsewhere on the board
GND: C36.1, SW2.1; also elsewhere on the board

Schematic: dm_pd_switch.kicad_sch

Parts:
C35: 100nF; C_0402; Voltage Rated 16V; Tolerance ±10%; Part CL05B104KO5NNNC; LCSC C1525
R55: 470Ω; R_0402; Overload Voltage (Max) 50V; Tolerance ±1%; Part 0402WGF4700TCE; LCSC C25117
SW1: TS-1088-AR02016; SW-SMD_L3.9-W3.0-P4.45; LCSC Part C720477

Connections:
/GPIO0: R55.2; also elsewhere on the board
GND: C35.1, SW1.1; also elsewhere on the board
unnamed: C35.2, R55.1, SW1.2

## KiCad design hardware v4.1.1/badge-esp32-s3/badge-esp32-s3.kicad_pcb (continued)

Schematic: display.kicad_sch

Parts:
P2: FPC 0.5MM 12P Pull type H2.0mm Pick up; FPC-SMD_12P-L11.5-W5.4-P0.50; LCSC Part C11086
R18: 100Ω; R_0402; Overload Voltage (Max) 50V; Tolerance ±1%; Part 0402WGF1000TCE; LCSC C25076
R39: 100kΩ; R_0402; Overload Voltage (Max) 50V; Tolerance ±1%; Part 0402WGF1003TCE; LCSC C25741
TP1, TP2, TP3, TP4, TP5: TestPoint; TestPoint_Pad_D1.5mm; not fitted
U7: HS20HS072RX-fpc; OLED-SMD_HS20HS072RX-pins_removed; LCSC Part C5329582

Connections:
+3.3V: P2.8 (IOVCC), P2.9 (VCC), R18.1; also elsewhere on the board
/GPIO0: P2.2 (CS), TP1.1; also elsewhere on the board
/GPIO1: P2.6 (RST), R39.1, TP5.1; also elsewhere on the board
/GPIO3: P2.5 (SDA), TP4.1; also elsewhere on the board
/GPIO45: P2.3 (RS), TP2.1; also elsewhere on the board
/GPIO46: P2.4 (SCL), TP3.1; also elsewhere on the board
GND: P2.1 (GND), P2.11 (K), P2.12 (GND), R39.2; also elsewhere on the board
unnamed: P2.10 (A), R18.2

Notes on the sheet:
Backlight always on
Default: Reset State

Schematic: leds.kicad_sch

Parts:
AL1, AL2, AL3, AL4, AL5, AL6, AL7, AL8, AL9, AL10, AL11, AL12, AL13, AL14, AL15, AL16, AL17, AL18, AL19, AL20, AL21, AL22, AL23, AL24: SK6805MICRO-J; LED-SMD_4P-SK6805MICRO-J; MPN SK6805MICRO-J; LCSC Part C2909056
C32, C33: 1uF; C_0402; Voltage Rated 25V; Tolerance ±10%; Part CL05A105KA5NQNC; LCSC C52923
D14: Red; D_0603; Part KT-0603R; LCSC C2286
LED1: RS-3535MWAM; LED-ARRAY-SMD_L3.7-W3.5-P1.10-TL; LCSC Part C842778
R20: 100Ω; R_0402; Overload Voltage (Max) 50V; Tolerance ±1%; Part 0402WGF1000TCE; LCSC C25076
R21, R24: 47Ω; R_0402; Overload Voltage (Max) 50V; Tolerance ±1%; Part 0402WGF470JTCE; LCSC C25118
R22: 300Ω; R_0402; Overload Voltage (Max) 50V; Tolerance ±1%; Part 0402WGF3000TCE; LCSC C25102
R68: 10kΩ; R_0402; Overload Voltage (Max) 50V; Tolerance ±1%; Part 0402WGF1002TCE; LCSC C25744

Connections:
/5V_stable: AL1.4 (VDD), AL2.4 (VDD), AL3.4 (VDD), AL4.4 (VDD), AL5.4 (VDD), AL6.4 (VDD), AL7.4 (VDD), AL8.4 (VDD), AL9.4 (VDD), AL10.4 (VDD), AL11.4 (VDD), AL12.4 (VDD), AL13.4 (VDD), AL14.4 (VDD), AL15.4 (VDD), AL16.4 (VDD), AL17.4 (VDD), AL18.4 (VDD), AL19.4 (VDD), AL20.4 (VDD), AL21.4 (VDD), AL22.4 (VDD), AL23.4 (VDD), AL24.4 (VDD), C32.1, C33.1; also elsewhere on the board
/AddrLedMid: AL1.3 (DIN), R68.1; also elsewhere on the board
/LEDSingleMid: R22.1; also elsewhere on the board
/LEDs/AL8_OUT: AL8.1 (DOUT), AL9.3 (DIN)
/LEDs/AL16_OUT: AL16.1 (DOUT), AL17.3 (DIN)
/RGBBlueMid: LED1.6 (+); also elsewhere on the board
/RGBGreenMid: LED1.5 (+); also elsewhere on the board
/RGBRedMid: LED1.4 (+); also elsewhere on the board
GND: AL1.2 (VSS), AL2.2 (VSS), AL3.2 (VSS), AL4.2 (VSS), AL5.2 (VSS), AL6.2 (VSS), AL7.2 (VSS), AL8.2 (VSS), AL9.2 (VSS), AL10.2 (VSS), AL11.2 (VSS), AL12.2 (VSS), AL13.2 (VSS), AL14.2 (VSS), AL15.2 (VSS), AL16.2 (VSS), AL17.2 (VSS), AL18.2 (VSS), AL19.2 (VSS), AL20.2 (VSS), AL21.2 (VSS), AL22.2 (VSS), AL23.2 (VSS), AL24.2 (VSS), C32.2, C33.2, D14.1, R20.2, R21.2, R24.2, R68.2; also elsewhere on the board
unnamed: AL1.1 (DOUT), AL2.3 (DIN)
unnamed: AL2.1 (DOUT), AL3.3 (DIN)
unnamed: AL3.1 (DOUT), AL4.3 (DIN)
unnamed: AL4.1 (DOUT), AL5.3 (DIN)
unnamed: AL5.1 (DOUT), AL6.3 (DIN)
unnamed: AL6.1 (DOUT), AL7.3 (DIN)
unnamed: AL7.1 (DOUT), AL8.3 (DIN)
unnamed: AL9.1 (DOUT), AL10.3 (DIN)
unnamed: AL10.1 (DOUT), AL11.3 (DIN)
unnamed: AL11.1 (DOUT), AL12.3 (DIN)
unnamed: AL12.1 (DOUT), AL13.3 (DIN)
unnamed: AL13.1 (DOUT), AL14.3 (DIN)
unnamed: AL14.1 (DOUT), AL15.3 (DIN)
unnamed: AL15.1 (DOUT), AL16.3 (DIN)
unnamed: AL17.1 (DOUT), AL18.3 (DIN)
unnamed: AL18.1 (DOUT), AL19.3 (DIN)
unnamed: AL19.1 (DOUT), AL20.3 (DIN)
unnamed: AL20.1 (DOUT), AL21.3 (DIN)
unnamed: AL21.1 (DOUT), AL22.3 (DIN)
unnamed: AL22.1 (DOUT), AL23.3 (DIN)
unnamed: AL23.1 (DOUT), AL24.3 (DIN)
unnamed: D14.2, R22.2
unnamed: LED1.1 (-), R21.1
unnamed: LED1.2 (-), R24.1
unnamed: LED1.3 (-), R20.1

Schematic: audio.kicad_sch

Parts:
BUZZER1: MLT-5020; BUZ-SMD_L5.0-W5.5-P4.60; LCSC Part C94598
Q5: DTC114E; DTC114EE; LCSC C94400
R2: 3362P-1-501_C48997906; RES-ADJ-TH_3362P; MPN 3362P-1-501; LCSC Part C48997906
R42: 27Ω; R_0402_1005Metric

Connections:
+3.3V: R2.3; also elsewhere on the board
/BuzzerMid: Q5.1 (B); also elsewhere on the board
GND: Q5.2 (E); also elsewhere on the board
unnamed: BUZZER1.1 (+), R42.2
unnamed: BUZZER1.2 (-), Q5.3 (C)
unnamed: R2.2, R42.1

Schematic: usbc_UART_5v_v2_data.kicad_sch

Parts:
C5: 10uF; C_0603; Voltage Rated 25V; Tolerance ±20%; Part CL10A106MA8NRNC; LCSC C96446
D2, D3, D4: LESD5D5.0CT1G; SOD-523_L1.2-W0.8-LS1.6-BI; LCSC Part C5199850
D5: B0520W; D_SOD-123; Part B0520W; LCSC C7502707
D17: SS32F_C719168; SMAF_L3.5-W2.6-LS4.7-RD; MPN SS32F; LCSC Part C719168
J1: Connector, USB-TYPE-C-16P; TYPE-C-SMD_HX-TYPE-C-16PIN; LCSC C2927039
R3, R4: 5.1kΩ; R_0402; Overload Voltage (Max) 50V; Tolerance ±1%; Part 0402WGF5101TCE; LCSC C25905

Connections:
/UART Interface/USB_DN: D3.2, J1.A7 (D-), J1.B7 (D-); also elsewhere on the board
/UART Interface/USB_DP: D2.2, J1.A6 (D+), J1.B6 (D+); also elsewhere on the board
/USB_HC: D17.1 (K); also elsewhere on the board
/USB_LC: D5.1; also elsewhere on the board
/VBUS: C5.1, D4.2, D5.2, D17.2 (A), J1.A9B4 (VBUS), J1.B9A4 (VBUS); also elsewhere on the board
GND: C5.2, D2.1, D3.1, D4.1, J1.A12B1 (GND), J1.B12A1 (GND), J1.S1 (SHIELD), R3.2, R4.2; also elsewhere on the board
unnamed: J1.A5 (CC1), R3.1
unnamed: J1.B5 (CC2), R4.1

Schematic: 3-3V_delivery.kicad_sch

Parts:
C25: 100nF; C_0402; Voltage Rated 16V; Tolerance ±10%; Part CL05B104KO5NNNC; LCSC C1525
C28, C29, C30, C31, C38, C40: 22uF; C_0805; LCSC C296720
C34, C44: 100nF; C_0402; Voltage Rated 50V; Tolerance ±10%; Part CL05B104KB54PNC; LCSC C307331
C37: TMK107BBJ106MA-T; C0603; LCSC Part C386081
C39: 10uF; C_0603; Voltage Rated 25V; Tolerance ±20%; Part CL10A106MA8NRNC; LCSC C96446
C43, C45: 10uF; C_0805; Voltage Rated 50V; Tolerance ±10%; Part GRM21BR61H106KE43L; LCSC C440198
D1: Red; D_0603; Part KT-0603R; LCSC C2286
L1: ANR4030T3R9M; IND-SMD_L4.0-W4.0; MPN ANR4030T3R9M; LCSC Part C6808101
L2: MPZ2012S101AT000; L0805; MPN MPZ2012S101AT000; LCSC Part C15957
L4: FTC404020S1R5MGCA; IND-SMD_L4.1-W4.1_SPM40XX; MPN FTC404020S1R5MGCA; LCSC Part C39676069
R19: 24kΩ; R_0402; Overload Voltage (Max) 50V; Tolerance ±1%; Part 0402WGF2402TCE; LCSC C25769; not fitted
R41: 150kΩ; R_0402; Overload Voltage (Max) 50V; Tolerance ±1%; Part 0402WGF1503TCE; LCSC C25755
R44, R46: 10kΩ; R_0402; Overload Voltage (Max) 50V; Tolerance ±1%; Part 0402WGF1002TCE; LCSC C25744
R53: 100kΩ; R_0402; Overload Voltage (Max) 50V; Tolerance ±1%; Part 0402WGF1003TCE; LCSC C25741
R54: 300Ω; R_0402; Overload Voltage (Max) 50V; Tolerance ±1%; Part 0402WGF3000TCE; LCSC C25102
R64: 0Ω; R_0402; Overload Voltage (Max) 50V; Tolerance ±1%; Part 0402WGF0000TCE; LCSC C17168
U2: TPS630701RNMR; VQFN-HR-15_L3.0-W2.5-P0.50-BL_TPS63070RNMR; LCSC Part C2876599
U9: AP63203WU-7; TSOT-26_L2.9-W1.6-P0.95-LS2.8-BL; MPN AP63203WU-7; LCSC Part C780769

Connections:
+3.3V: C28.1, C29.1, D1.2, L1.2, R64.1; also elsewhere on the board
/5V_stable: C30.1, C31.1, C37.2, C40.1, L2.1, R53.1, U2.5 (FB), U2.7 (VOUT), U2.8 (VOUT); also elsewhere on the board
/BatteryVoltage: C34.1, R41.2, R44.1; also elsewhere on the board
/Voltage Management/SW: C44.2, L1.1, U9.5 (SW)
/Voltage Management/VIN: C38.1, L2.2, U9.2 (EN), U9.3 (VIN)
GND: C25.2, C28.2, C29.2, C30.2, C31.2, C34.2, C37.1, C38.2, C39.2, C40.2, C43.2, C45.2, R19.2, R44.2, R54.1, U2.1 (PS/SYNC), U2.4 (GND), U2.6 (FB2), U2.10 (PGND), U2.15 (VSEL), U9.4 (GND); also elsewhere on the board
unnamed: D1.1, R54.2
unnamed: R46.2, U2.14 (EN)
unnamed: L4.1, U2.11 (L1)
unnamed: L4.2, U2.9 (L2)
unnamed: R53.2, U2.2 (PG)
unnamed: C25.1, U2.3 (VAUX)
unnamed: C44.1, U9.6 (BST)
unnamed: R19.1, R64.2, U9.1 (FB)
PWR_RAW: C39.1, C43.1, C45.1, R41.1, R46.1, U2.12 (VIN), U2.13 (VIN); also elsewhere on the board

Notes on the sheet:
FB: 0.8V
2A Max
Divides Voltage by 16 to map to the ESP 0dB attenuation mode
There are fixed and adjustable versions of this chip. We perferably want to get the 3.3V fixed one but if we can't an adjustable version with 75k and 24k resistor to set the FB will do. If a fixed version is used, replace the R64 with 0R and DNP R19 Fixed version: AP63203WU-7 (C780769) Adjustable: 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

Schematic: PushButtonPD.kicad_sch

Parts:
C18: 1uF; C_0603; Voltage Rated 50V; Tolerance ±10%; Part CL10A105KB8NNNC; LCSC C15849
R27, R28: 10kΩ; R_0603; Overload Voltage (Max) 75V; Tolerance ±1%; Part 0603WAF1002T5E; LCSC C25804
SW4: TS665CJ; SW-TH_4P-L6.0-W6.0-P4.50-LS6.5; LCSC Part C393938

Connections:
+3.3V: SW4.2 (B); also elsewhere on the board
/LeftButtonMid: C18.1, R28.2; also elsewhere on the board
GND: C18.2, R27.2; also elsewhere on the board
unnamed: R27.1, R28.1, SW4.4 (D)

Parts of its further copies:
C19, C20, C21, C23: 1uF; C_0603; Voltage Rated 50V; Tolerance ±10%; Part CL10A105KB8NNNC; LCSC C15849
R29, R30, R31, R32, R33, R34, R37, R38: 10kΩ; R_0603; Overload Voltage (Max) 75V; Tolerance ±1%; Part 0603WAF1002T5E; LCSC C25804
SW5, SW6, SW7, SW9: TS665CJ; SW-TH_4P-L6.0-W6.0-P4.50-LS6.5; LCSC Part C393938

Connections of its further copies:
+3.3V: SW5.2 (B), SW6.2 (B), SW7.2 (B), SW9.2 (B); also elsewhere on the board
/BButtonMid: C21.1, R34.2; also elsewhere on the board
/DownButtonMid: C23.1, R38.2; also elsewhere on the board
/RightButtonMid: C20.1, R32.2; also elsewhere on the board
/UpButtonMid: C19.1, R30.2; also elsewhere on the board
GND: C19.2, C20.2, C21.2, C23.2, R29.2, R31.2, R33.2, R37.2; also elsewhere on the board
unnamed: R29.1, R30.1, SW5.4 (D)
unnamed: R31.1, R32.1, SW6.4 (D)
unnamed: R33.1, R34.1, SW7.4 (D)
unnamed: R37.1, R38.1, SW9.4 (D)

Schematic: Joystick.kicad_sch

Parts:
R23: YF16-FL7.2-B5KA(45-10)-R-A28; JOYTICK-TH_YF16-DFL7.2-B5KO-45-10-B5KO-55--RG-A22; LCSC Part C37323739

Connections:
+3.3V: R23.3, R23.4; also elsewhere on the board
/JoystickXMid: R23.2; also elsewhere on the board
/JoystickYMid: R23.5; also elsewhere on the board
GND: R23.1, R23.6, R23.7 (shell), R23.8 (shell), R23.9 (shell), R23.10 (shell); also elsewhere on the board

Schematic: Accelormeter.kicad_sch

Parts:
C10, C11: 100nF; C_0402; Voltage Rated 16V; Tolerance ±10%; Part CL05B104KO5NNNC; LCSC C1525
C26: 4.7uF; C_0603; Voltage Rated 16V; Tolerance ±10%; Part CL10A475KO8NNNC; LCSC C19666
R43, R45: 4.7kΩ; R_0402; Overload Voltage (Max) 50V; Tolerance ±1%; Part 0402WGF4701TCE; LCSC C25900
U18: MMA8452QR1_C11360; QFN-16_L3.0-W3.0-P0.50-TL_MMA8452QR1; LCSC Part C11360

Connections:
+3.3V: C10.1, C26.2, R43.1, R45.1, U18.1 (VDDIO), U18.14 (VDD); also elsewhere on the board
/GPIO41: R45.2, U18.6 (SDA); also elsewhere on the board
/GPIO42: R43.2, U18.4 (SCL); also elsewhere on the board
/Onboard Peripheral/Accelormeter/INT 1 (output to MCU, NN): U18.11 (INT1); also elsewhere on the board
/Onboard Peripheral/Accelormeter/INT 2 (output to MCU, NN): U18.9 (INT2); also elsewhere on the board
GND: C10.2, C11.2, C26.1, U18.5 (GND), U18.7 (SA0), U18.10 (GND), U18.12 (GND); also elsewhere on the board
unnamed: C11.1, U18.2 (BYP)

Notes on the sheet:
With SA0 Low, 001110 (0x1C) is the address, if high, its (0x1D)
Place 4.7uF Close to VDD

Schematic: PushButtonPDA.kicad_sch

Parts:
C22: 1uF; C_0603; Voltage Rated 50V; Tolerance ±10%; Part CL10A105KB8NNNC; LCSC C15849
R35, R36: 10kΩ; R_0603; Overload Voltage (Max) 75V; Tolerance ±1%; Part 0603WAF1002T5E; LCSC C25804
SW8: TS665CJ; SW-TH_4P-L6.0-W6.0-P4.50-LS6.5; LCSC Part C393938

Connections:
+3.3V: SW8.2 (B); also elsewhere on the board
/AButtonMid: C22.1, R36.2; also elsewhere on the board
GND: C22.2, R35.2; also elsewhere on the board
unnamed: R35.1, R36.1, SW8.3 (C)

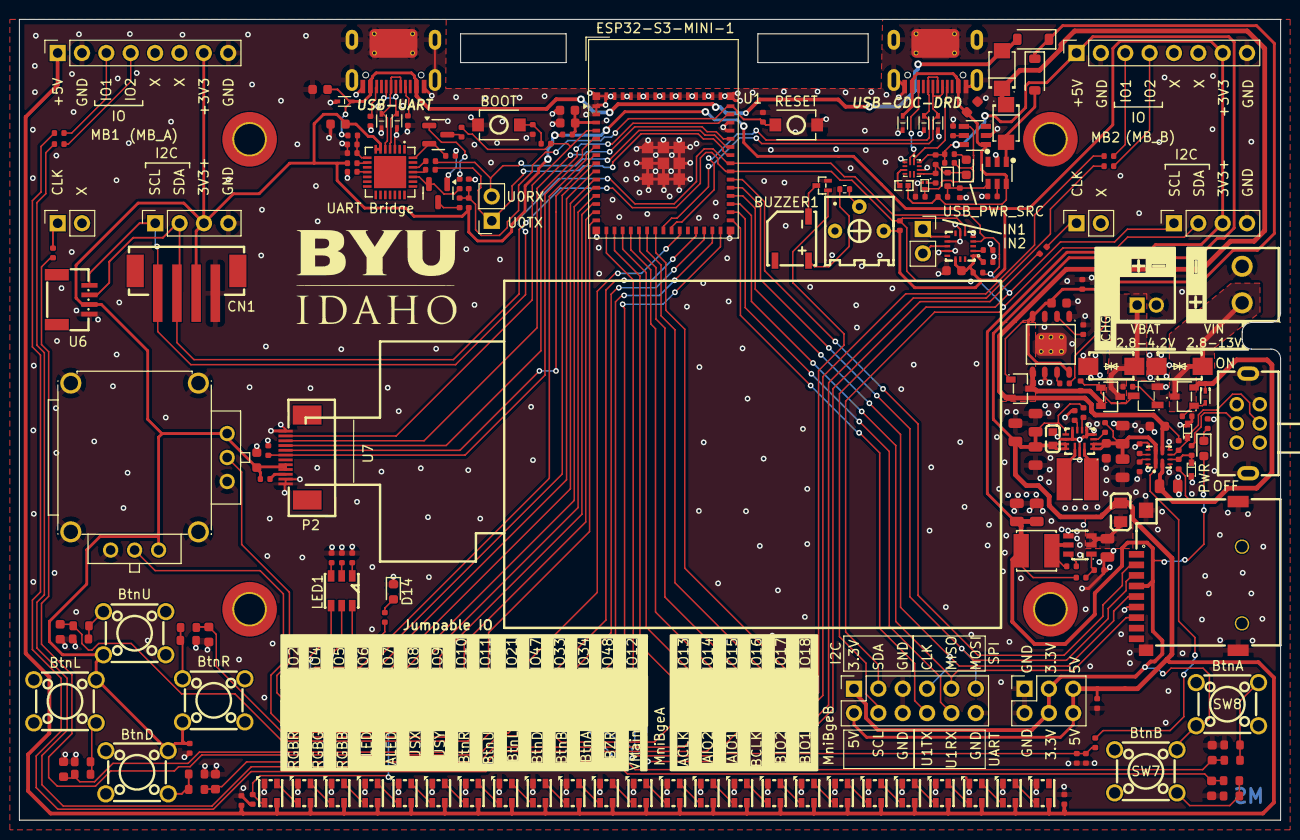
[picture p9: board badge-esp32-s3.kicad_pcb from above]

Board: 2 copper layers, 131.5 x 83.5 mm, 215 parts (0 on the bottom side), 167 nets.

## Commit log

2025-05-14 Allow PDFs under the docs directory only (reference schematics)
2025-05-14 Add ESP32-S3-DevkitC reference schematic
2025-05-15 Add bare kicad project, lcsc part library using easyeda2kicad
    [badge-esp32-s3.kicad_pcb, badge-esp32-s3.kicad_sch]
2025-05-16 Alternate schematic reference
2025-05-16 KiCad library updates
2025-05-16 Update board requirements
2025-05-16 Trim library Take advantage of existing libraries https://github.com/CDFER/JLCPCB-Kicad-Library
2025-05-16 Add ESD diodes to part library
2025-05-16 Marginal kicad schematic update
    [badge-esp32-s3.kicad_sch]
2025-05-17 Add diode from ESP devkit schematic
2025-05-17 Finish USB sub-schematic
    [3-3V_delivery.kicad_sch, badge-esp32-s3.kicad_sch, usbc_5v_v2_data.kicad_sch]
2025-05-17 Put lcsc-lib in it's own path, some 3D model tweaks
    [badge-esp32-s3.kicad_pcb]
2025-05-18 Finish linear regulator, start uart interface
    [3-3V_delivery.kicad_sch, uart_interface.kicad_sch, usbc_5v_v2_data.kicad_sch]
2025-05-21 Finish USB-UART subcircuit
    [3-3V_delivery.kicad_sch, badge-esp32-s3.kicad_sch, uart_interface.kicad_sch]
2025-05-21 Schematic on par with basic devkit
    [badge-esp32-s3.kicad_sch, pd_switch.kicad_sch, uart_interface.kicad_sch]
2025-05-22 add display block
    [badge-esp32-s3.kicad_sch, display.kicad_sch, pd_switch.kicad_sch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]
2025-05-23 Add I2C GPIO expander to library
2025-06-06 Add empty sub schematics
    [Charging.kicad_sch, audio.kicad_sch, badge-esp32-s3.kicad_sch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]
2025-06-06 More reference schematics and datasheets
2025-06-06 Make progress on charger, switch out some diodes
    [3-3V_delivery.kicad_sch, Charging.kicad_sch, usbc_5v_v2_data.kicad_sch]
2025-06-10 add new linear regulator that works with battery
2025-06-10 Finish charging circuit Switched out schottky diodes Better linear regulator
    [3-3V_delivery.kicad_sch, Charging.kicad_sch, usbc_5v_v2_data.kicad_sch]
2026-02-26 added v4.0 hardware
    [3-3V_delivery.kicad_sch, Accelormeter.kicad_sch, Charging.kicad_sch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]
2026-02-26 fixed labeling on 5V pin
    [badge-esp32-s3.kicad_pcb]
2026-02-26 added 470R resistor to boot switch to prevent conflict
    [badge-esp32-s3.kicad_pcb, badge-esp32-s3.kicad_sch, bom.csv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]
2026-03-25 fixed silkscreen error
    fixed silkscreen error, produced gerber files and allowed gerber zip to pass through gitignore.
    [badge-esp32-s3.kicad_pcb]
2026-06-30 added DRD, 3.3V switching reg, and VIN
    [3-3V_delivery.kicad_sch, Charging.kicad_sch, badge-esp32-s3.kicad_sch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]
2026-06-30 break before make circuit
    [usbc_esp_5v_v2_data.kicad_sch]
2026-07-14 finished schematics and layout
    [3-3V_delivery.kicad_sch, Charging.kicad_sch, badge-esp32-s3.kicad_pcb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]
2026-07-14 changed buzzer pot
    [Charging.kicad_sch, audio.kicad_sch, badge-esp32-s3.kicad_pcb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]
2026-07-14 fixed silkscreen discrepancy. Added change-log
    [badge-esp32-s3.kicad_pcb, bom-adjusted for missing parts.xls]
2026-07-15 changed PWR switch and current limit
    [Charging.kicad_sch, badge-esp32-s3.kicad_pcb, bom-adjusted for missing parts.xls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]
2026-08-04 cleaned up folders
    [3-3V_delivery.kicad_sch, Accelormeter.kicad_sch, Charging.kicad_sch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]
2026-08-04 removed duplicate
    [3-3V_delivery.kicad_sch, Accelormeter.kicad_sch, Charging.kicad_sch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]
2026-08-04 recreated folders
    [3-3V_delivery.kicad_sch, Accelormeter.kicad_sch, Charging.kicad_sch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]
2026-08-24 fixed out of stock components
    [3-3V_delivery.kicad_sch, Charging.kicad_sch, adjustments.csv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]
2026-08-24 fixed file extension
    [adjustments.csv, adjustments.xlsx]
2026-09-29 changed 3.3V reg from adj to fixed
    changed 3.3V reg from adj to fixed and reflexed that in the bom
    [3-3V_delivery.kicad_sch, Charging.kicad_sch, badge-esp32-s3.kicad_pcb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]
2026-10-16 changed silkscreen for LED references
2026-10-16 changed LED referenced to be on silkscreen layer instead of Fab layer
